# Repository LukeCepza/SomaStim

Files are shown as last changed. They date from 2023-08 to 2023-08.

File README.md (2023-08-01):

### Repository of NeuroSense Somatosensory Stimulation Devices. 
Folders are arranged in Four parts: \
 &nbsp;&nbsp;&nbsp;&nbsp;   1. Electronics Diagrams \
 &nbsp;&nbsp;&nbsp;&nbsp;   2. Firmware \
 &nbsp;&nbsp;&nbsp;&nbsp;   3. Prototypes designs \
 &nbsp;&nbsp;&nbsp;&nbsp;   4. OpenVibe Experiment Modules 

Each of these folders contain subfolders for each module (some may not include a Master Module subfolder): \
 &nbsp;&nbsp;&nbsp;&nbsp;   1. Air \
 &nbsp;&nbsp;&nbsp;&nbsp;   2. Caress \
 &nbsp;&nbsp;&nbsp;&nbsp;   3. Vibration \
 &nbsp;&nbsp;&nbsp;&nbsp;   4. Master 

There is an extra folder with other functions \
Designed by Luke Cepza \
Neurotechs Research Group

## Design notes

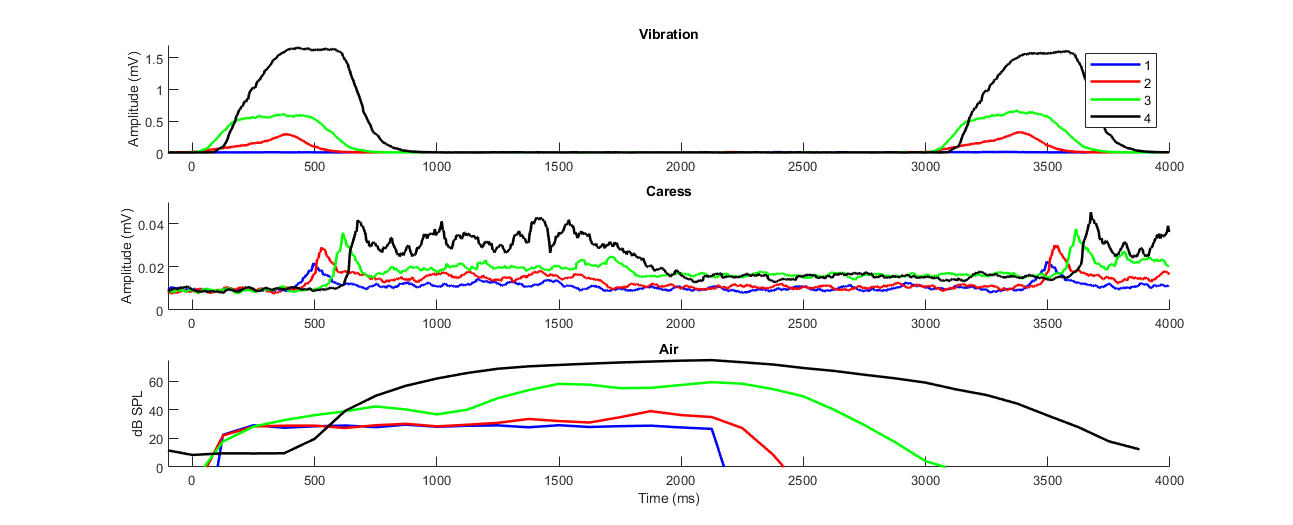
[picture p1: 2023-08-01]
Others/Matlab/sos.tif

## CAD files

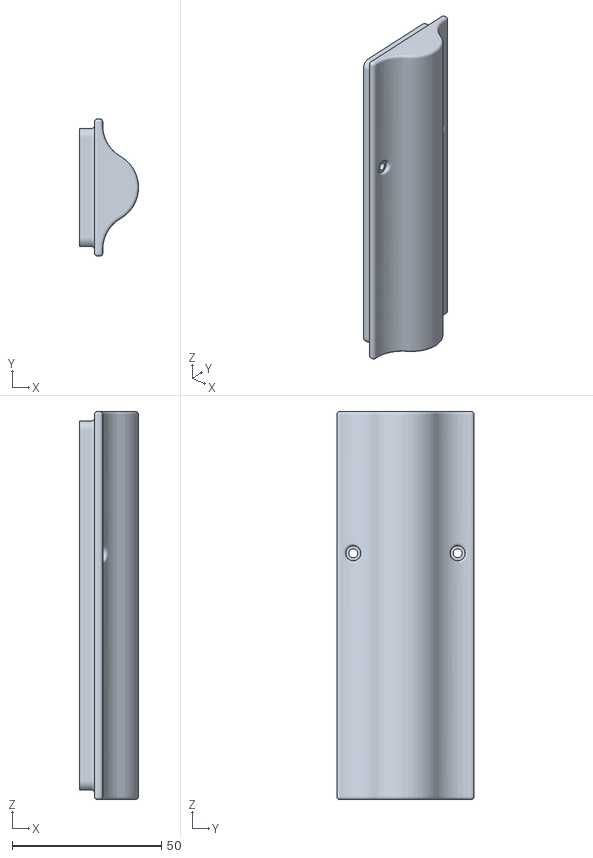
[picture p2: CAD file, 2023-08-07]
Design/VibrationModule/VibrationBox_NeuroSense_SLDPRT_STL - copia/VibracionFull - V_BatteryBoxLid-1.STL
19.8 x 46.0 x 130.0

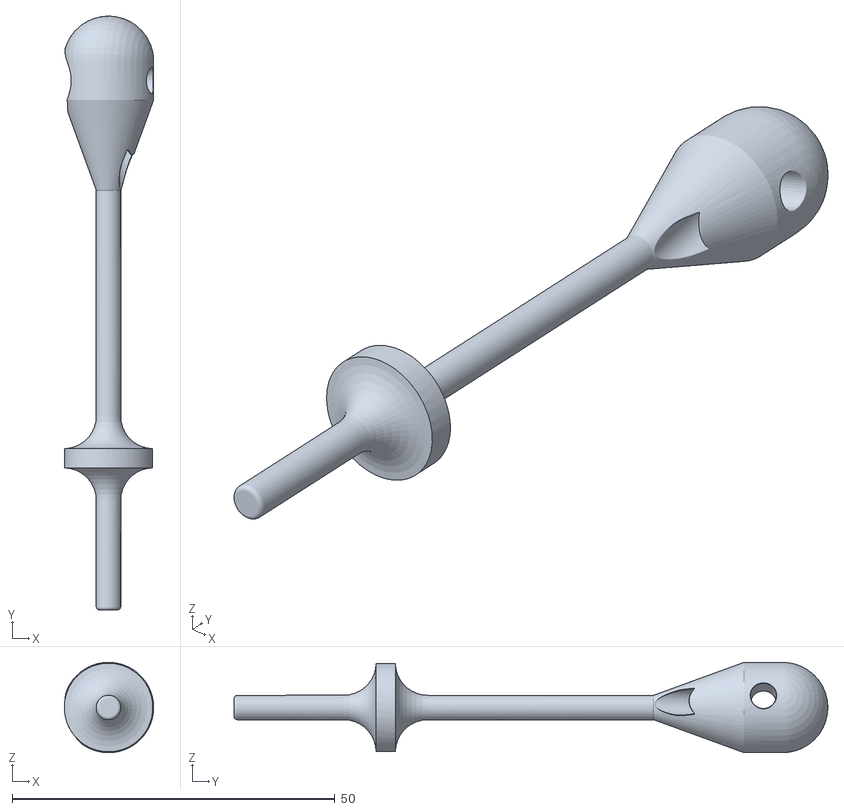
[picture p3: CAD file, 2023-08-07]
Design/VibrationModule/VibrationUpwards_NeuroSense_SLDPRT_STL/Ensamblaje1 - MotorHolderV4-1.STL
13.8 x 92.0 x 14.0

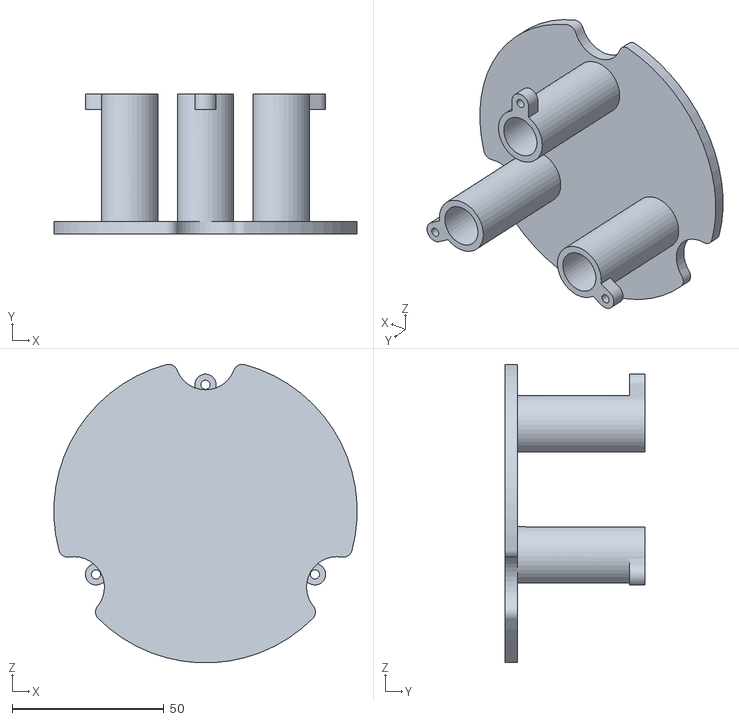
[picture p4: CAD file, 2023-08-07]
Design/VibrationModule/VibrationUpwards_NeuroSense_SLDPRT_STL/Ensamblaje1 - BaseV2-1.STL
99.9 x 46.0 x 98.3

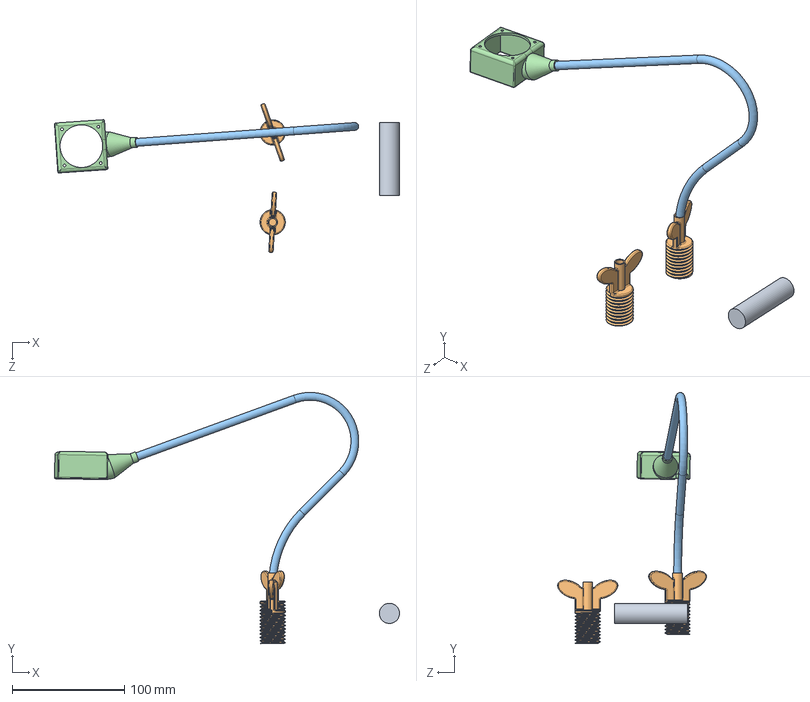
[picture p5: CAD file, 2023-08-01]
Design/AirModule_NeuroSense_SLDPRT_STL/AirModule.SLDASM
307.3 x 223.8 x 132.6 mm
A_FanScrewBase x 2
Pipe
A_FanBoxTilted

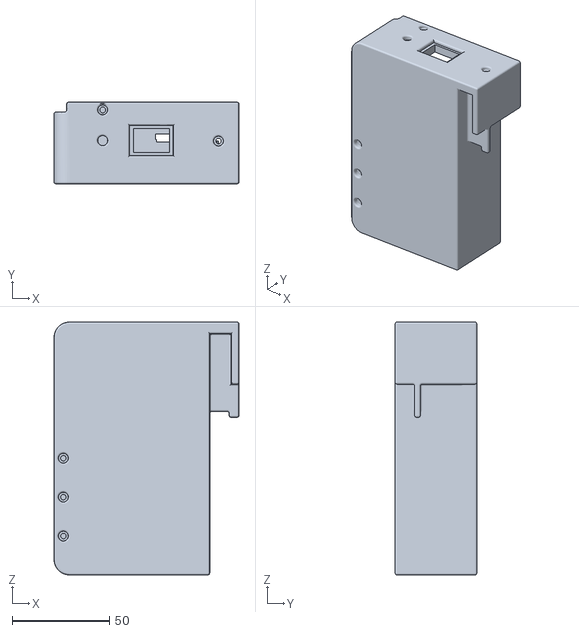
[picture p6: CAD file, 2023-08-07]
Design/VibrationModule/VibrationBox_NeuroSense_SLDPRT_STL - copia/VibracionFull - V_ElectroBox-1.STL
95.0 x 42.0 x 130.0

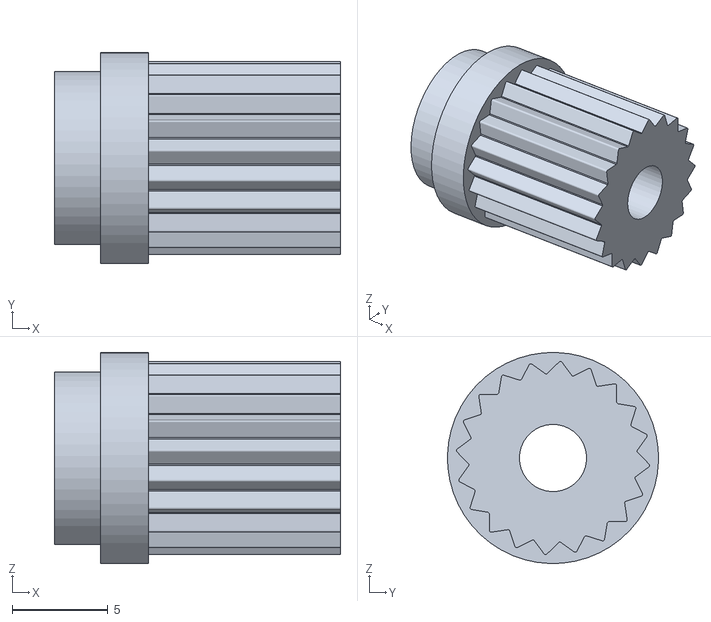
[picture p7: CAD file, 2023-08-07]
Design/CaressModule_NeuroSense_SLDPRT_STL/CaricasFull - T_MD_CouplingMotor-1.STL
14.9 x 11.0 x 11.0

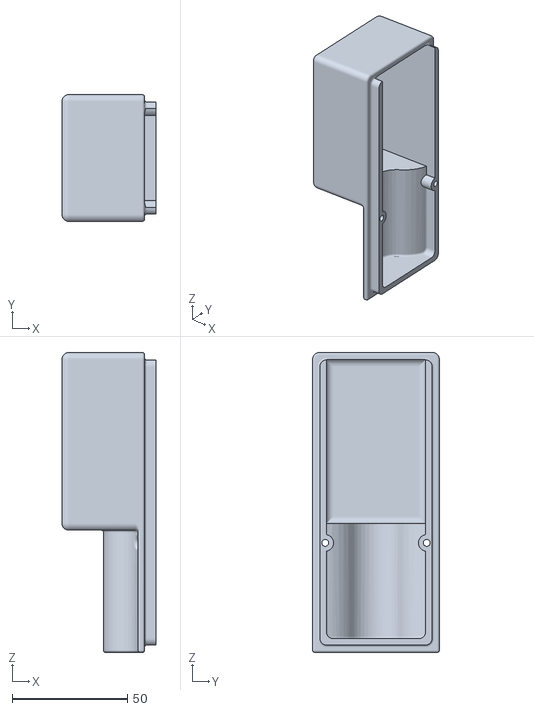
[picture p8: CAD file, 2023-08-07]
Design/CaressModule_NeuroSense_SLDPRT_STL/CaricasFull - T_MD_BatteryPackLid-1.STL
40.8 x 55.0 x 130.0

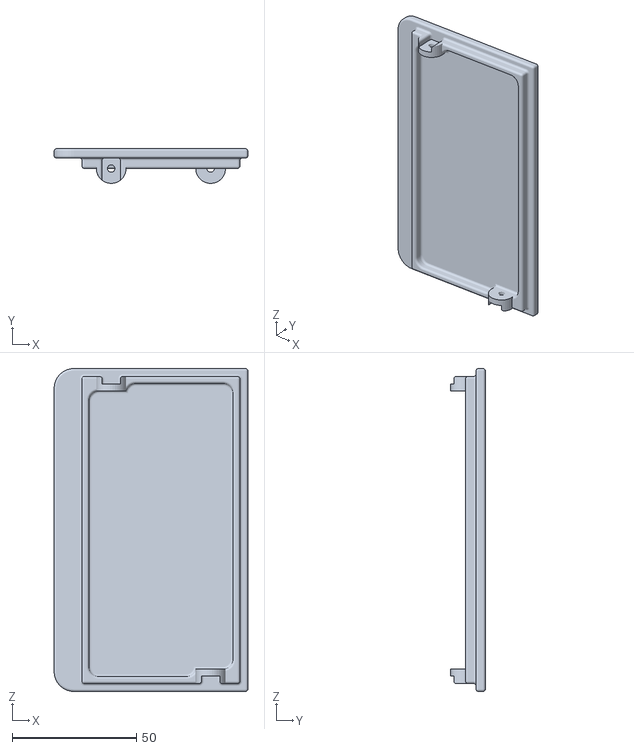
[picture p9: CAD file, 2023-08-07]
Design/VibrationModule/VibrationBox_NeuroSense_SLDPRT_STL - copia/VibracionFull - V_ElectroBoxLid-1.STL
78.0 x 14.0 x 130.0

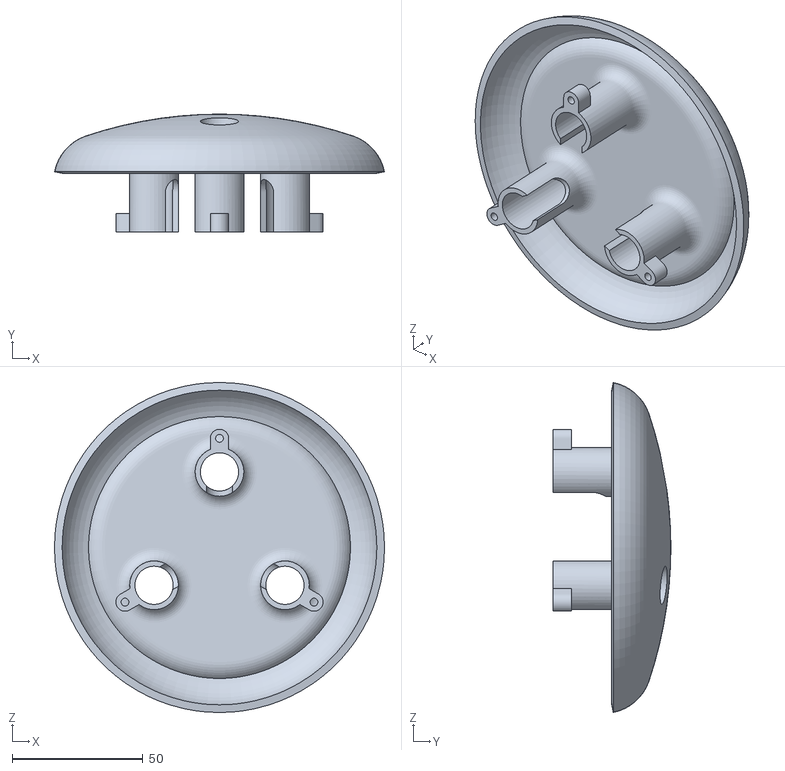
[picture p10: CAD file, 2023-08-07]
Design/VibrationModule/VibrationUpwards_NeuroSense_SLDPRT_STL/Ensamblaje1 - Upper-1.STL
126.0 x 45.0 x 126.0

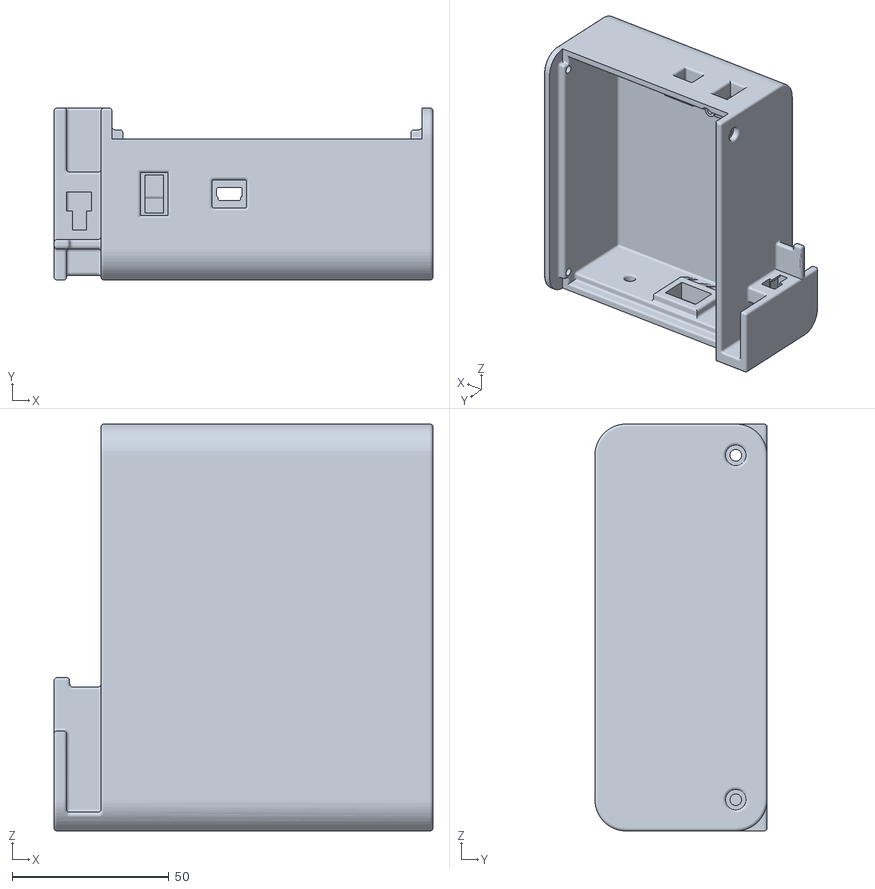
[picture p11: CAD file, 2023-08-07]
Design/CaressModule_NeuroSense_SLDPRT_STL/CaricasFull - T_MD_BaseElectroV2-1.STL
121.0 x 55.0 x 130.0

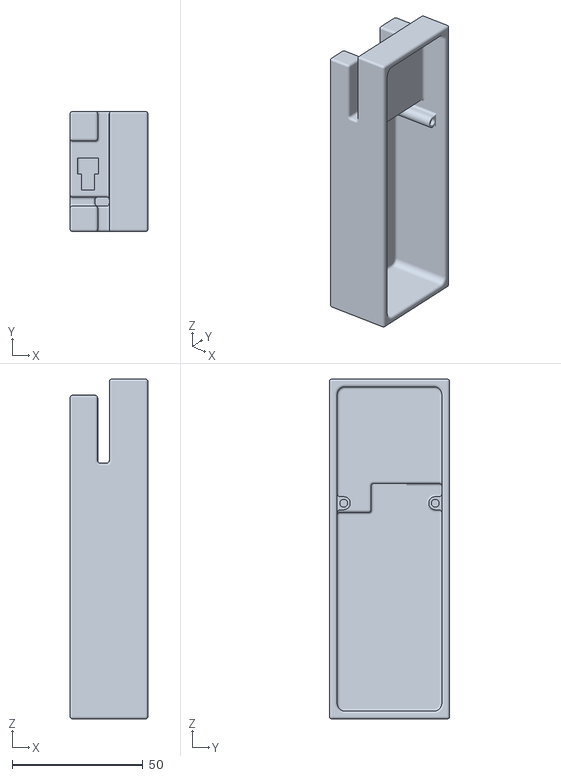
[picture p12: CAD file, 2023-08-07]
Design/VibrationModule/VibrationBox_NeuroSense_SLDPRT_STL - copia/VibracionFull - V_BatteryBox-1.STL
29.8 x 46.0 x 130.0

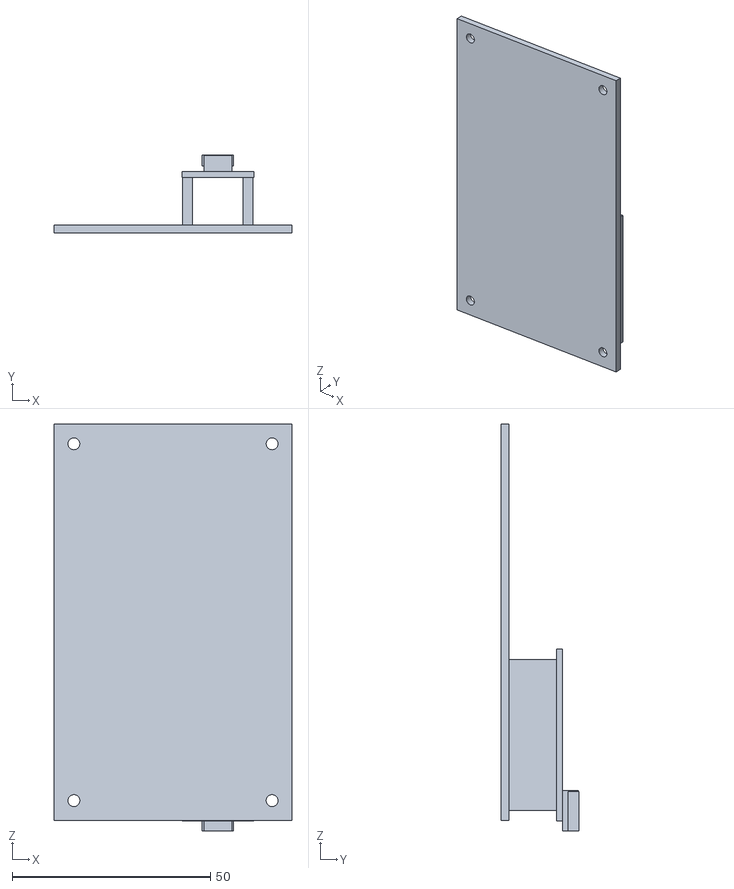
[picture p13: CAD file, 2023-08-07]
Design/VibrationModule/VibrationBox_NeuroSense_SLDPRT_STL - copia/VibracionFull - V_PCB-1.STL
60.0 x 19.7 x 102.7

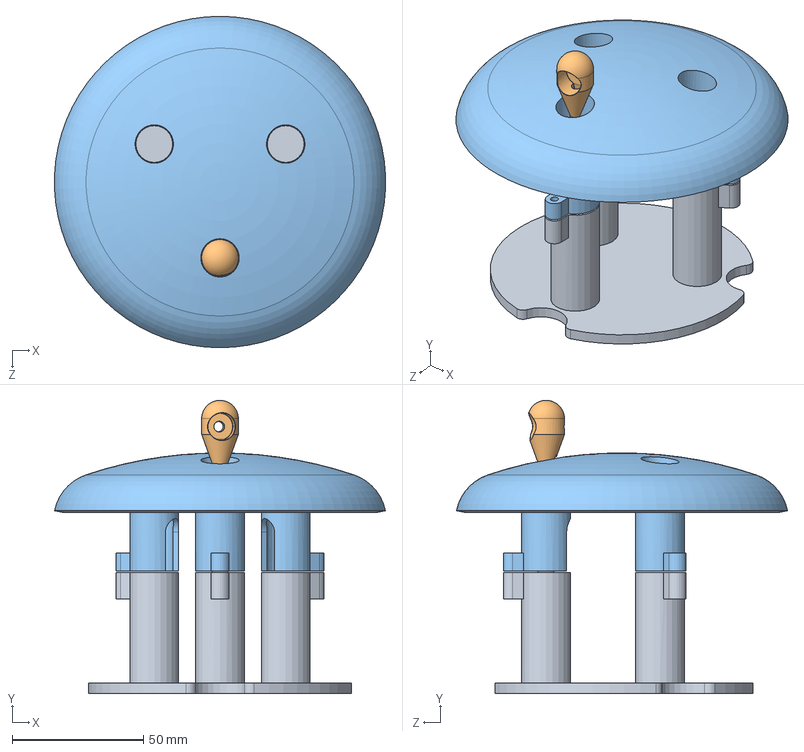
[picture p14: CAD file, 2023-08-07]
Design/VibrationModule/VibrationUpwards_NeuroSense_SLDPRT_STL/Ensamblaje1.SLDASM
125.9 x 111.6 x 126.0 mm
BaseV2
MotorHolderV4
Upper

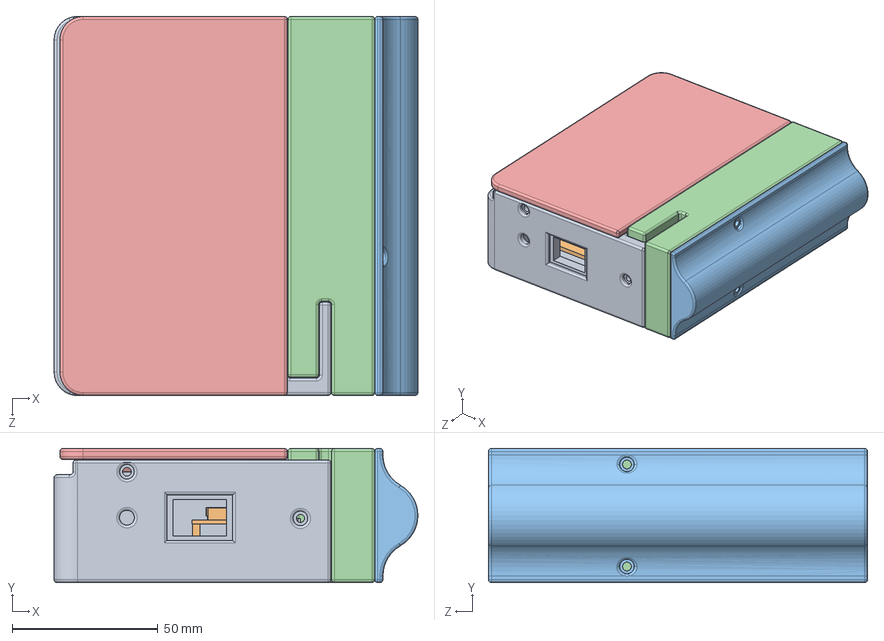
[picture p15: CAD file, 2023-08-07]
Design/VibrationModule/VibrationBox_NeuroSense_SLDPRT_STL - copia/VibracionFull.SLDASM
124.8 x 46.0 x 130.0 mm
V_ElectroBox
V_PCB
V_BatteryBoxLid
V_BatteryBox
V_ElectroBoxLid

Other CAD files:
Design/CaressModule_NeuroSense_SLDPRT_STL/CaricasFull - T_MD_LoadCell-1.STL
Design/CaressModule_NeuroSense_SLDPRT_STL/CaricasFull - T_MD_RollerAxis-1.STL
Design/CaressModule_NeuroSense_SLDPRT_STL/CaricasFull - T_MD_MotorSupport-1.STL
Design/CaressModule_NeuroSense_SLDPRT_STL/CaricasFull - T_MD_LateralBehind-1.STL
Design/AirModule_NeuroSense_SLDPRT_STL/18650.SLDPRT
Design/AirModule_NeuroSense_SLDPRT_STL/A_BatteryBox.SLDPRT
Design/AirModule_NeuroSense_SLDPRT_STL/A_BatteryBoxLid.SLDPRT
Design/AirModule_NeuroSense_SLDPRT_STL/A_ElectroBox.SLDPRT
Design/AirModule_NeuroSense_SLDPRT_STL/A_ElectroBoxLid.SLDPRT
Design/AirModule_NeuroSense_SLDPRT_STL/A_FanBoxTilted.SLDPRT
Design/AirModule_NeuroSense_SLDPRT_STL/A_FanScrewBase.SLDPRT
Design/AirModule_NeuroSense_SLDPRT_STL/AirModule - 18650-1.STL
Design/AirModule_NeuroSense_SLDPRT_STL/AirModule - A_BatteryBox-1.STL
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

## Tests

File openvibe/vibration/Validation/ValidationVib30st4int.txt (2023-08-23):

-- this function is called when the box is initialized
function initialize(box)
	dofile(box:get_config("${Path_Data}") .. "/plugins/stimulation/lua-stimulator-stimcodes.lua")
end

-- this function is called when the box is uninitialized
function uninitialize(box)
	io.write("uninitialize has been calle d\n")
end

function process(box)
	io.write("process has been called\n")
	box:send_stimulation(1,33084,2,0)	--Start LSL communication
		
	-- stimuli labels
	-- 33032, vibration 1/4
	-- 33033, vibration 2/4
	-- 33034, vibration 3/4
	-- 33035, vibration 4/4
	-- 33042, stop stimulus
	
box:send_stimulation(1, 33032, 5, 0)
box:send_stimulation(1, 33032, 7, 0)
box:send_stimulation(1, 33032, 9, 0)
box:send_stimulation(1, 33032, 11, 0)
box:send_stimulation(1, 33032, 13, 0)
box:send_stimulation(1, 33032, 15, 0)
box:send_stimulation(1, 33032, 17, 0)
box:send_stimulation(1, 33032, 19, 0)
box:send_stimulation(1, 33032, 21, 0)
box:send_stimulation(1, 33032, 23, 0)
box:send_stimulation(1, 33032, 25, 0)
box:send_stimulation(1, 33032, 27, 0)
box:send_stimulation(1, 33032, 29, 0)
box:send_stimulation(1, 33032, 31, 0)
box:send_stimulation(1, 33032, 33, 0)
box:send_stimulation(1, 33032, 35, 0)
box:send_stimulation(1, 33032, 37, 0)
box:send_stimulation(1, 33032, 39, 0)
box:send_stimulation(1, 33032, 41, 0)
box:send_stimulation(1, 33032, 43, 0)
box:send_stimulation(1, 33032, 45, 0)
box:send_stimulation(1, 33032, 47, 0)
box:send_stimulation(1, 33032, 49, 0)
box:send_stimulation(1, 33032, 51, 0)
box:send_stimulation(1, 33032, 53, 0)
box:send_stimulation(1, 33032, 55, 0)
box:send_stimulation(1, 33032, 57, 0)
box:send_stimulation(1, 33032, 59, 0)
box:send_stimulation(1, 33032, 61, 0)
box:send_stimulation(1, 33032, 63, 0)
box:send_stimulation(1, 33042, 5.5, 0)
box:send_stimulation(1, 33042, 7.5, 0)
box:send_stimulation(1, 33042, 9.5, 0)
box:send_stimulation(1, 33042, 11.5, 0)
box:send_stimulation(1, 33042, 13.5, 0)
box:send_stimulation(1, 33042, 15.5, 0)
box:send_stimulation(1, 33042, 17.5, 0)
box:send_stimulation(1, 33042, 19.5, 0)
box:send_stimulation(1, 33042, 21.5, 0)
box:send_stimulation(1, 33042, 23.5, 0)
box:send_stimulation(1, 33042, 25.5, 0)
box:send_stimulation(1, 33042, 27.5, 0)
box:send_stimulation(1, 33042, 29.5, 0)
box:send_stimulation(1, 33042, 31.5, 0)
box:send_stimulation(1, 33042, 33.5, 0)
box:send_stimulation(1, 33042, 35.5, 0)
box:send_stimulation(1, 33042, 37.5, 0)
box:send_stimulation(1, 33042, 39.5, 0)
box:send_stimulation(1, 33042, 41.5, 0)
box:send_stimulation(1, 33042, 43.5, 0)
box:send_stimulation(1, 33042, 45.5, 0)
box:send_stimulation(1, 33042, 47.5, 0)
box:send_stimulation(1, 33042, 49.5, 0)
box:send_stimulation(1, 33042, 51.5, 0)
box:send_stimulation(1, 33042, 53.5, 0)
box:send_stimulation(1, 33042, 55.5, 0)
box:send_stimulation(1, 33042, 57.5, 0)
box:send_stimulation(1, 33042, 59.5, 0)
box:send_stimulation(1, 33042, 61.5, 0)
box:send_stimulation(1, 33042, 63.5, 0)

box:send_stimulation(1, 33033, 65, 0)
box:send_stimulation(1, 33033, 67, 0)
box:send_stimulation(1, 33033, 69, 0)
box:send_stimulation(1, 33033, 71, 0)
box:send_stimulation(1, 33033, 73, 0)
box:send_stimulation(1, 33033, 75, 0)
box:send_stimulation(1, 33033, 77, 0)
box:send_stimulation(1, 33033, 79, 0)
box:send_stimulation(1, 33033, 81, 0)
box:send_stimulation(1, 33033, 83, 0)
box:send_stimulation(1, 33033, 85, 0)
box:send_stimulation(1, 33033, 87, 0)
box:send_stimulation(1, 33033, 89, 0)
box:send_stimulation(1, 33033, 91, 0)
box:send_stimulation(1, 33033, 93, 0)
box:send_stimulation(1, 33033, 95, 0)
box:send_stimulation(1, 33033, 97, 0)
box:send_stimulation(1, 33033, 99, 0)
box:send_stimulation(1, 33033, 101, 0)
box:send_stimulation(1, 33033, 103, 0)
box:send_stimulation(1, 33033, 105, 0)
box:send_stimulation(1, 33033, 107, 0)
box:send_stimulation(1, 33033, 109, 0)
box:send_stimulation(1, 33033, 111, 0)
box:send_stimulation(1, 33033, 113, 0)
box:send_stimulation(1, 33033, 115, 0)
box:send_stimulation(1, 33033, 117, 0)
box:send_stimulation(1, 33033, 119, 0)
box:send_stimulation(1, 33033, 121, 0)
box:send_stimulation(1, 33033, 123, 0)
box:send_stimulation(1, 33042, 65.5, 0)
box:send_stimulation(1, 33042, 67.5, 0)
box:send_stimulation(1, 33042, 69.5, 0)
box:send_stimulation(1, 33042, 71.5, 0)
box:send_stimulation(1, 33042, 73.5, 0)
box:send_stimulation(1, 33042, 75.5, 0)
box:send_stimulation(1, 33042, 77.5, 0)
box:send_stimulation(1, 33042, 79.5, 0)
box:send_stimulation(1, 33042, 81.5, 0)
box:send_stimulation(1, 33042, 83.5, 0)
box:send_stimulation(1, 33042, 85.5, 0)
box:send_stimulation(1, 33042, 87.5, 0)
box:send_stimulation(1, 33042, 89.5, 0)
box:send_stimulation(1, 33042, 91.5, 0)
box:send_stimulation(1, 33042, 93.5, 0)
box:send_stimulation(1, 33042, 95.5, 0)
box:send_stimulation(1, 33042, 97.5, 0)
box:send_stimulation(1, 33042, 99.5, 0)
box:send_stimulation(1, 33042, 101.5, 0)
box:send_stimulation(1, 33042, 103.5, 0)
box:send_stimulation(1, 33042, 105.5, 0)
box:send_stimulation(1, 33042, 107.5, 0)
box:send_stimulation(1, 33042, 109.5, 0)
box:send_stimulation(1, 33042, 111.5, 0)
box:send_stimulation(1, 33042, 113.5, 0)
box:send_stimulation(1, 33042, 115.5, 0)
box:send_stimulation(1, 33042, 117.5, 0)
box:send_stimulation(1, 33042, 119.5, 0)
box:send_stimulation(1, 33042, 121.5, 0)
box:send_stimulation(1, 33042, 123.5, 0)

box:send_stimulation(1, 33034, 125, 0)
box:send_stimulation(1, 33034, 127, 0)
box:send_stimulation(1, 33034, 129, 0)
box:send_stimulation(1, 33034, 131, 0)
box:send_stimulation(1, 33034, 133, 0)
box:send_stimulation(1, 33034, 135, 0)
box:send_stimulation(1, 33034, 137, 0)
box:send_stimulation(1, 33034, 139, 0)
box:send_stimulation(1, 33034, 141, 0)
box:send_stimulation(1, 33034, 143, 0)
box:send_stimulation(1, 33034, 145, 0)
box:send_stimulation(1, 33034, 147, 0)
box:send_stimulation(1, 33034, 149, 0)
box:send_stimulation(1, 33034, 151, 0)
box:send_stimulation(1, 33034, 153, 0)
box:send_stimulation(1, 33034, 155, 0)
box:send_stimulation(1, 33034, 157, 0)
box:send_stimulation(1, 33034, 159, 0)
box:send_stimulation(1, 33034, 161, 0)
box:send_stimulation(1, 33034, 163, 0)
box:send_stimulation(1, 33034, 165, 0)
box:send_stimulation(1, 33034, 167, 0)
box:send_stimulation(1, 33034, 169, 0)
box:send_stimulation(1, 33034, 171, 0)
box:send_stimulation(1, 33034, 173, 0)
box:send_stimulation(1, 33034, 175, 0)
box:send_stimulation(1, 33034, 177, 0)
box:send_stimulation(1, 33034, 179, 0)
box:send_stimulation(1, 33034, 181, 0)
box:send_stimulation(1, 33034, 183, 0)
box:send_stimulation(1, 33042, 125.5, 0)
box:send_stimulation(1, 33042, 127.5, 0)
box:send_stimulation(1, 33042, 129.5, 0)
box:send_stimulation(1, 33042, 131.5, 0)
box:send_stimulation(1, 33042, 133.5, 0)
box:send_stimulation(1, 33042, 135.5, 0)
box:send_stimulation(1, 33042, 137.5, 0)
box:send_stimulation(1, 33042, 139.5, 0)
box:send_stimulation(1, 33042, 141.5, 0)
box:send_stimulation(1, 33042, 143.5, 0)
box:send_stimulation(1, 33042, 145.5, 0)
box:send_stimulation(1, 33042, 147.5, 0)
box:send_stimulation(1, 33042, 149.5, 0)
box:send_stimulation(1, 33042, 151.5, 0)
box:send_stimulation(1, 33042, 153.5, 0)
box:send_stimulation(1, 33042, 155.5, 0)
box:send_stimulation(1, 33042, 157.5, 0)
box:send_stimulation(1, 33042, 159.5, 0)
box:send_stimulation(1, 33042, 161.5, 0)
box:send_stimulation(1, 33042, 163.5, 0)
box:send_stimulation(1, 33042, 165.5, 0)
box:send_stimulation(1, 33042, 167.5, 0)
box:send_stimulation(1, 33042, 169.5, 0)
box:send_stimulation(1, 33042, 171.5, 0)
box:send_stimulation(1, 33042, 173.5, 0)
box:send_stimulation(1, 33042, 175.5, 0)
box:send_stimulation(1, 33042, 177.5, 0)
box:send_stimulation(1, 33042, 179.5, 0)
box:send_stimulation(1, 33042, 181.5, 0)
box:send_stimulation(1, 33042, 183.5, 0)

box:send_stimulation(1, 33035, 185, 0)
box:send_stimulation(1, 33035, 187, 0)
box:send_stimulation(1, 33035, 189, 0)
box:send_stimulation(1, 33035, 191, 0)
box:send_stimulation(1, 33035, 193, 0)
box:send_stimulation(1, 33035, 195, 0)
box:send_stimulation(1, 33035, 197, 0)
box:send_stimulation(1, 33035, 199, 0)
box:send_stimulation(1, 33035, 201, 0)
box:send_stimulation(1, 33035, 203, 0)
box:send_stimulation(1, 33035, 205, 0)
box:send_stimulation(1, 33035, 207, 0)
box:send_stimulation(1, 33035, 209, 0)
box:send_stimulation(1, 33035, 211, 0)
box:send_stimulation(1, 33035, 213, 0)
box:send_stimulation(1, 33035, 215, 0)
box:send_stimulation(1, 33035, 217, 0)
box:send_stimulation(1, 33035, 219, 0)
box:send_stimulation(1, 33035, 221, 0)
box:send_stimulation(1, 33035, 223, 0)
box:send_stimulation(1, 33035, 225, 0)
box:send_stimulation(1, 33035, 227, 0)
box:send_stimulation(1, 33035, 229, 0)
box:send_stimulation(1, 33035, 231, 0)
box:send_stimulation(1, 33035, 233, 0)
box:send_stimulation(1, 33035, 235, 0)
box:send_stimulation(1, 33035, 237, 0)
box:send_stimulation(1, 33035, 239, 0)
box:send_stimulation(1, 33035, 241, 0)
box:send_stimulation(1, 33035, 243, 0)
box:send_stimulation(1, 33042, 185.5, 0)
box:send_stimulation(1, 33042, 187.5, 0)
box:send_stimulation(1, 33042, 189.5, 0)
box:send_stimulation(1, 33042, 191.5, 0)
box:send_stimulation(1, 33042, 193.5, 0)
box:send_stimulation(1, 33042, 195.5, 0)
box:send_stimulation(1, 33042, 197.5, 0)
box:send_stimulation(1, 33042, 199.5, 0)
box:send_stimulation(1, 33042, 201.5, 0)
box:send_stimulation(1, 33042, 203.5, 0)
box:send_stimulation(1, 33042, 205.5, 0)
box:send_stimulation(1, 33042, 207.5, 0)
box:send_stimulation(1, 33042, 209.5, 0)
box:send_stimulation(1, 33042, 211.5, 0)
box:send_stimulation(1, 33042, 213.5, 0)
box:send_stimulation(1, 33042, 215.5, 0)
box:send_stimulation(1, 33042, 217.5, 0)
box:send_stimulation(1, 33042, 219.5, 0)
box:send_stimulation(1, 33042, 221.5, 0)
box:send_stimulation(1, 33042, 223.5, 0)
box:send_stimulation(1, 33042, 225.5, 0)
box:send_stimulation(1, 33042, 227.5, 0)
box:send_stimulation(1, 33042, 229.5, 0)
box:send_stimulation(1, 33042, 231.5, 0)
box:send_stimulation(1, 33042, 233.5, 0)
box:send_stimulation(1, 33042, 235.5, 0)
box:send_stimulation(1, 33042, 237.5, 0)
box:send_stimulation(1, 33042, 239.5, 0)
box:send_stimulation(1, 33042, 241.5, 0)
box:send_stimulation(1, 33042, 243.5, 0)

	box:send_stimulation(1, 32770, 303, 0)	-- End paradigm
	box:send_stimulation(1, 32770, 305, 0) 
	
	box:sleep()				-- releases cpu

end

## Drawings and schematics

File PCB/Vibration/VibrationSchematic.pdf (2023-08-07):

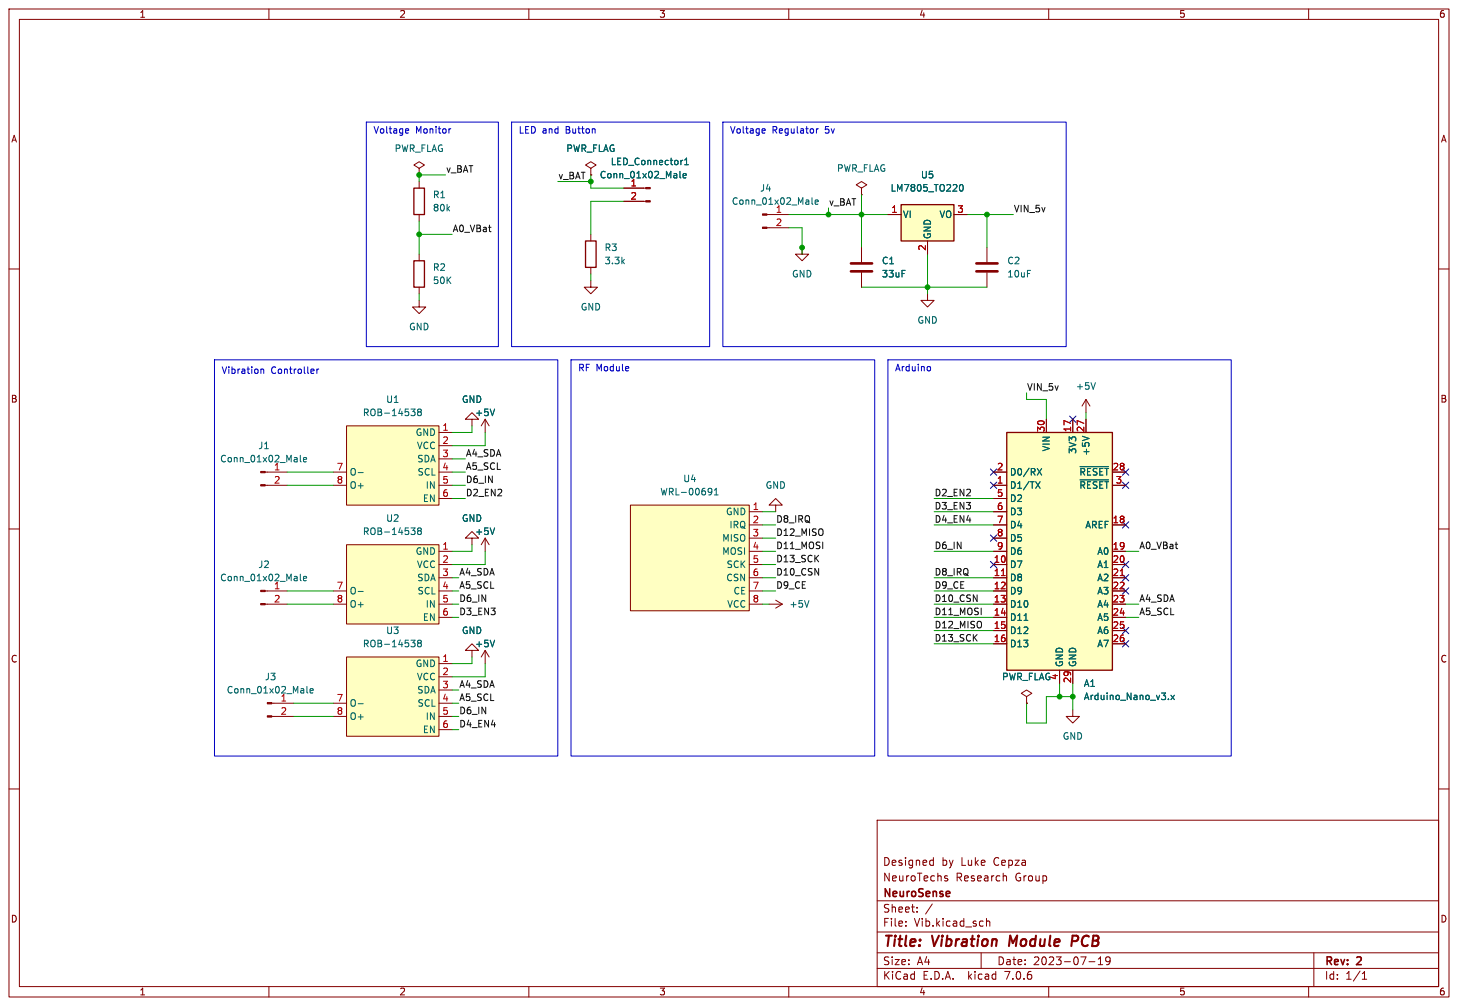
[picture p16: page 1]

Id: 1/1 Title: Vibration Module PCB

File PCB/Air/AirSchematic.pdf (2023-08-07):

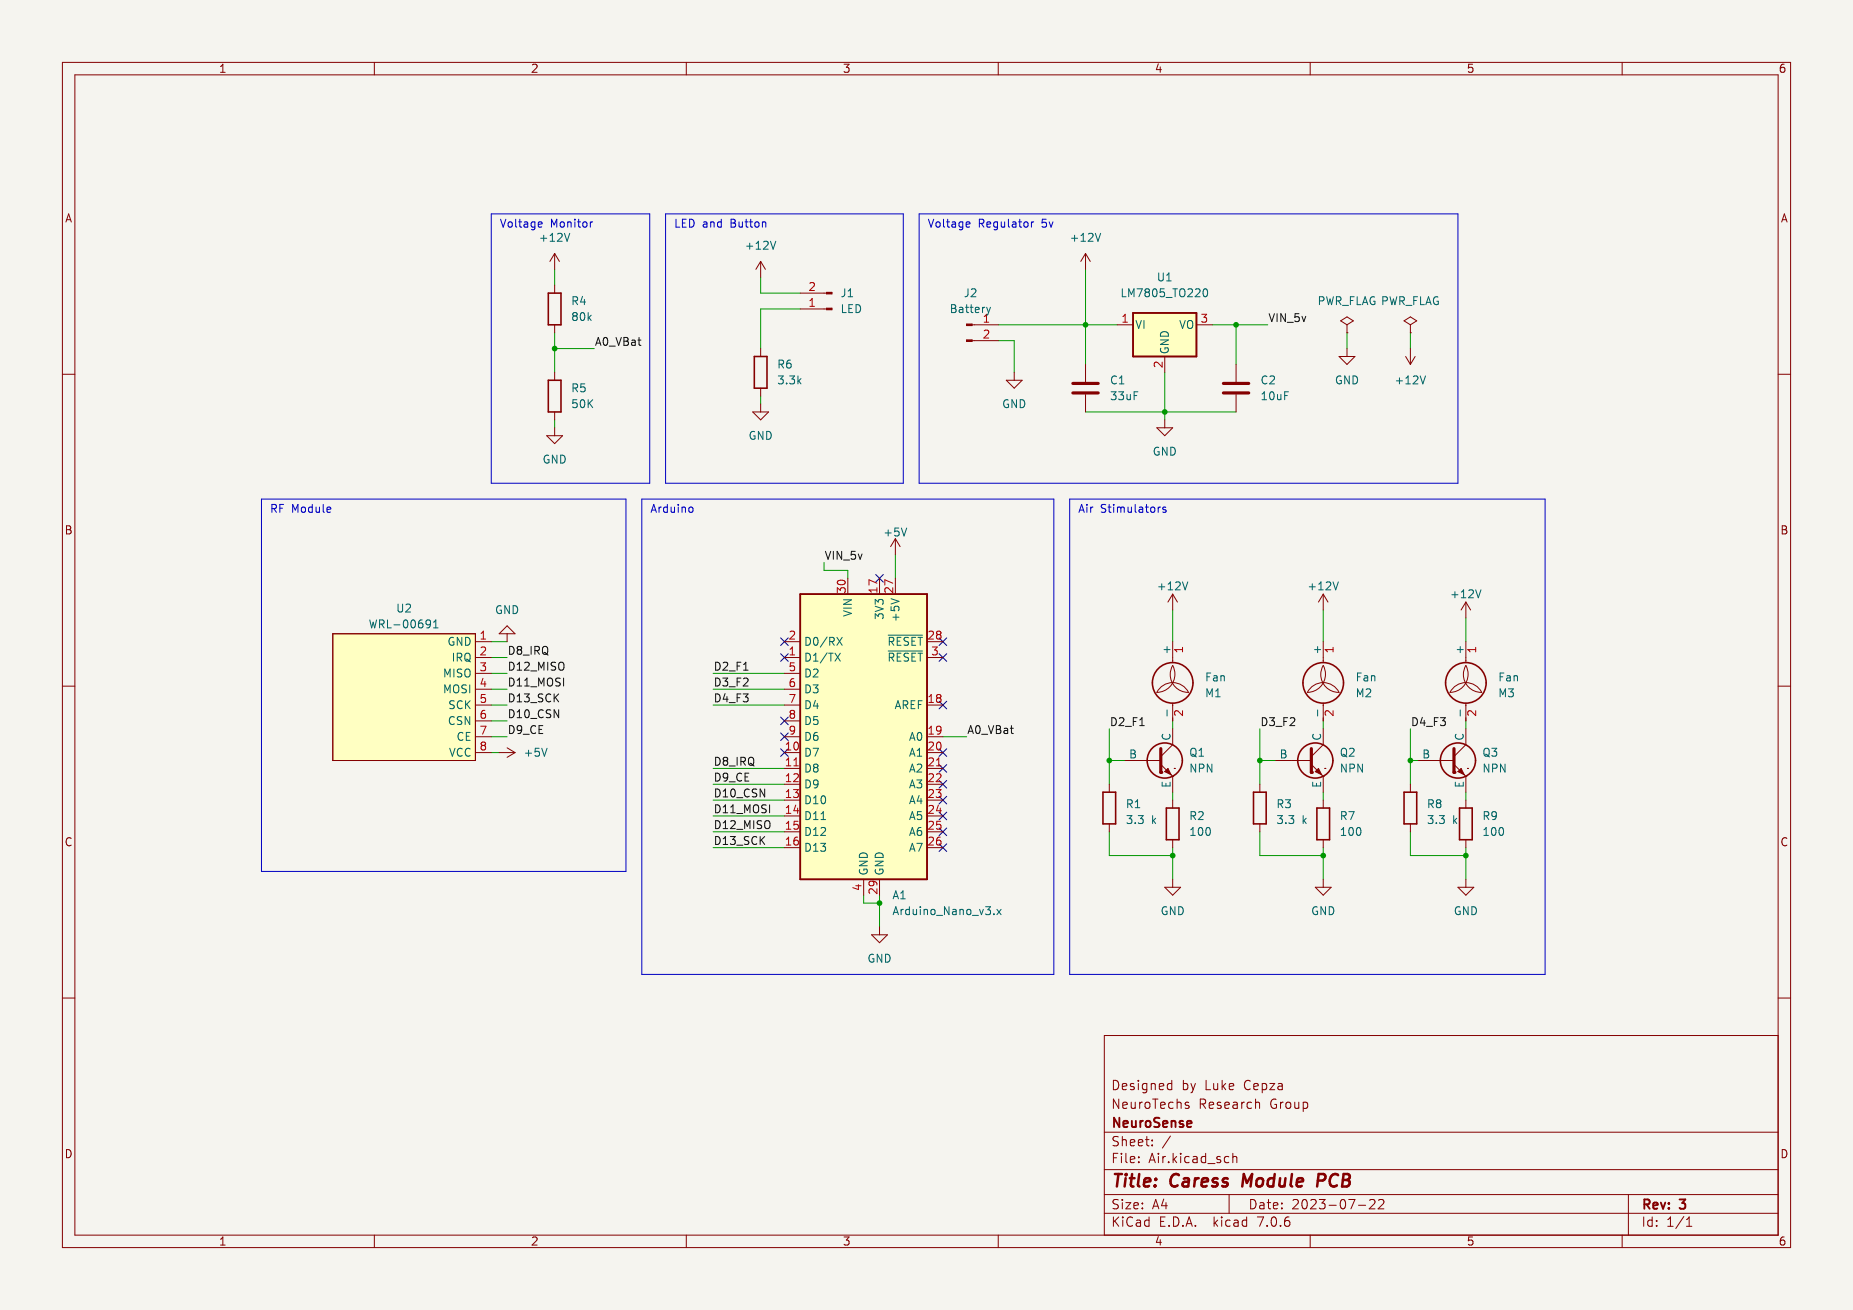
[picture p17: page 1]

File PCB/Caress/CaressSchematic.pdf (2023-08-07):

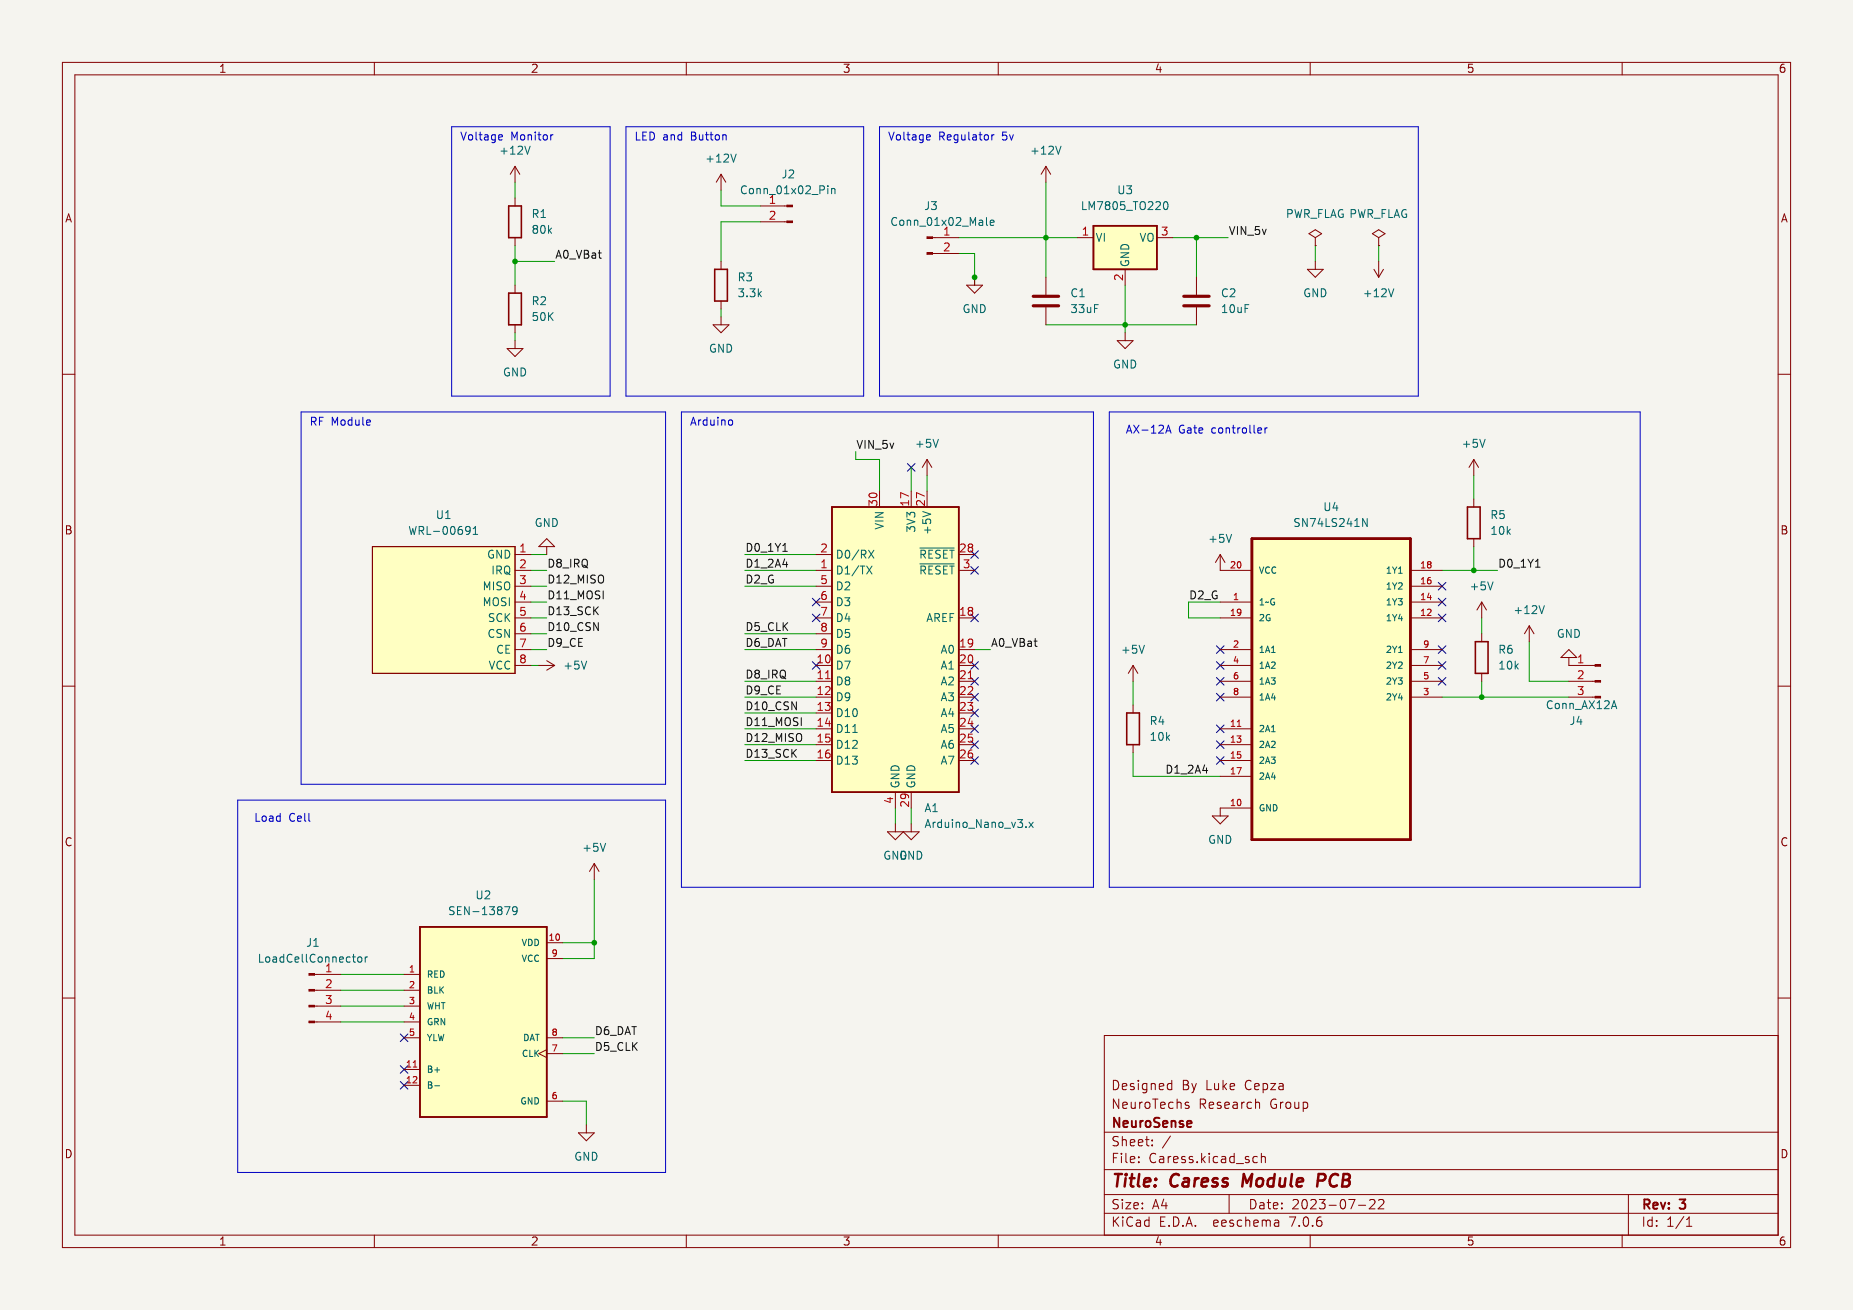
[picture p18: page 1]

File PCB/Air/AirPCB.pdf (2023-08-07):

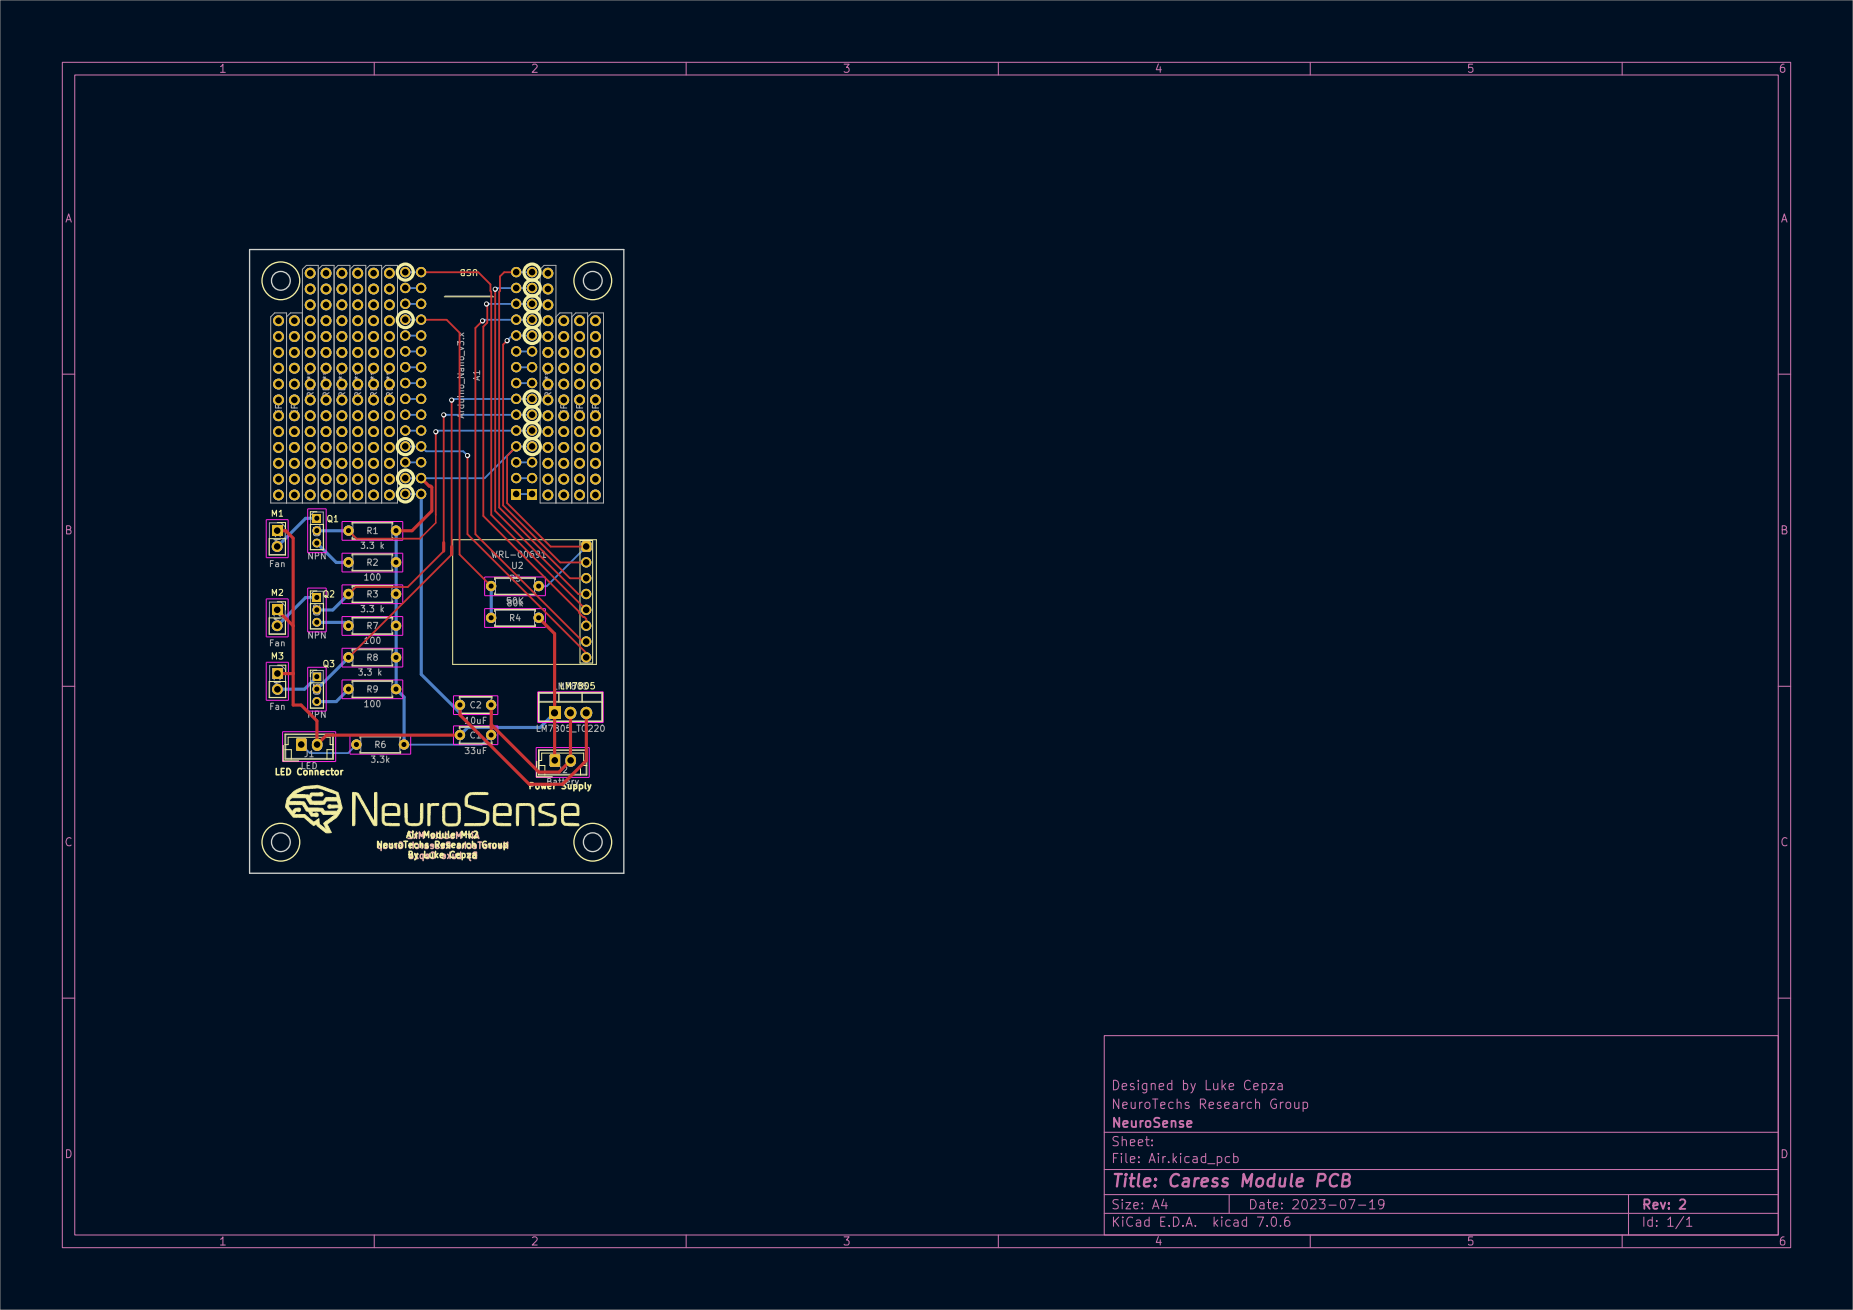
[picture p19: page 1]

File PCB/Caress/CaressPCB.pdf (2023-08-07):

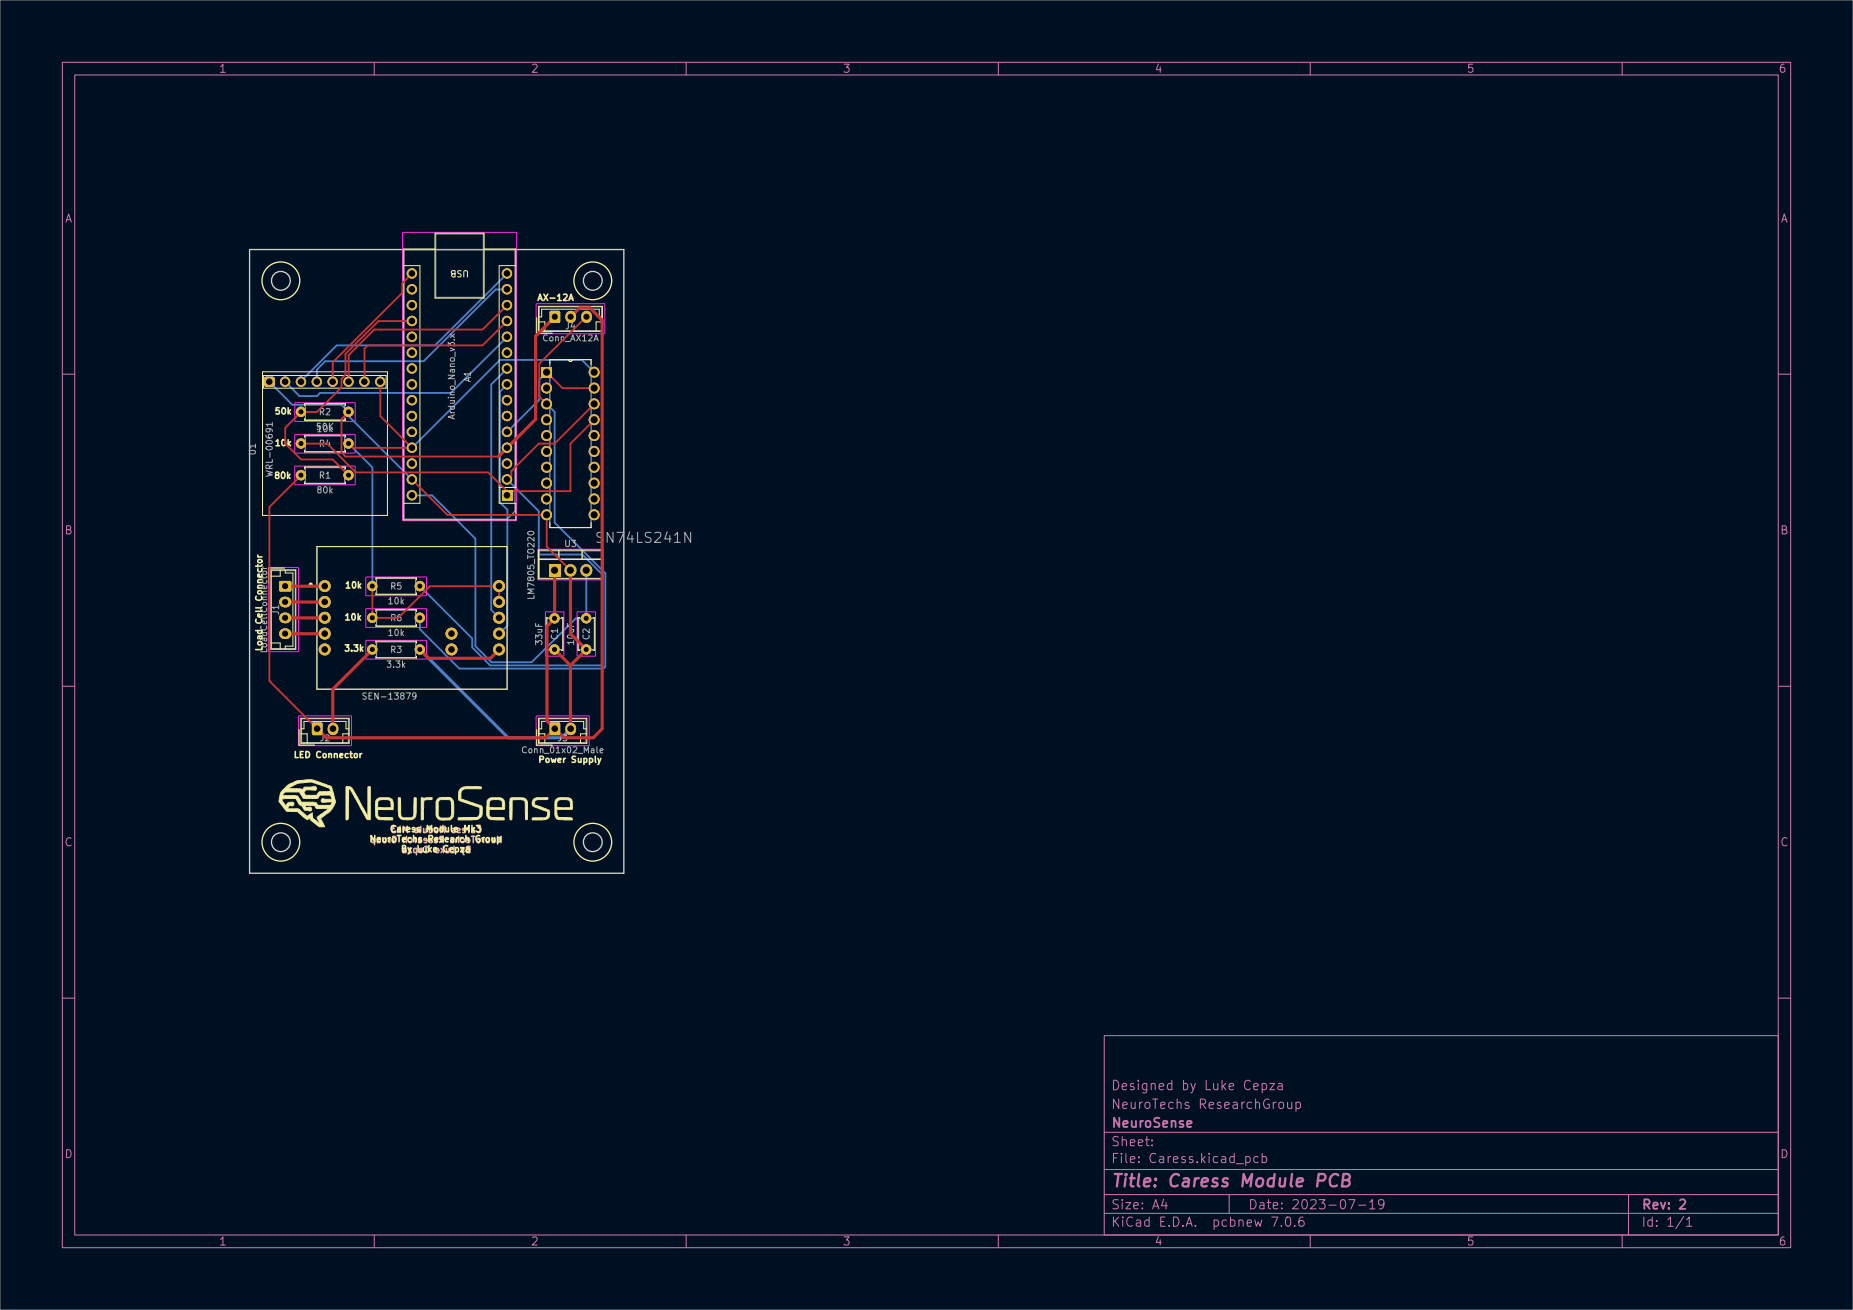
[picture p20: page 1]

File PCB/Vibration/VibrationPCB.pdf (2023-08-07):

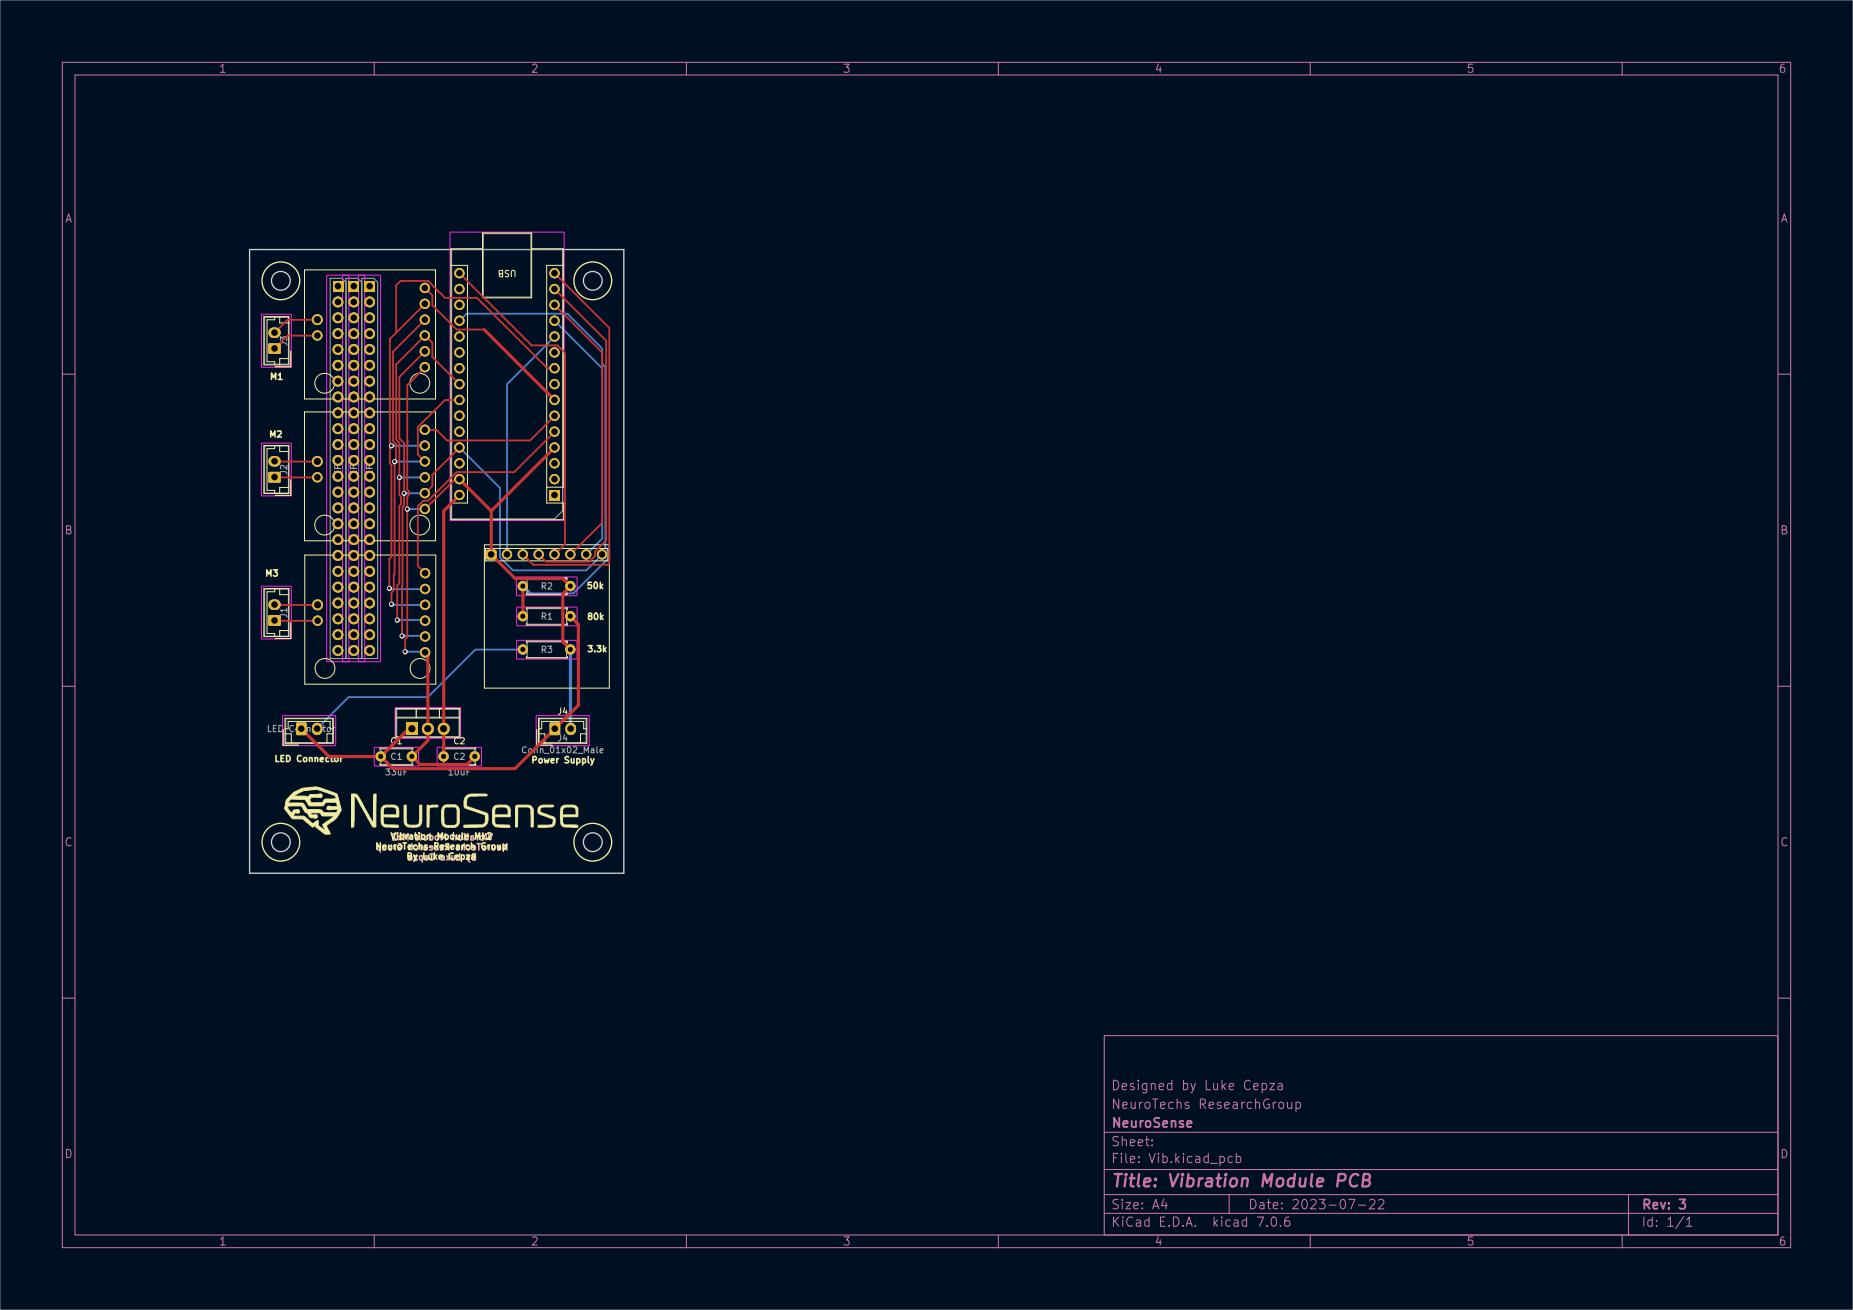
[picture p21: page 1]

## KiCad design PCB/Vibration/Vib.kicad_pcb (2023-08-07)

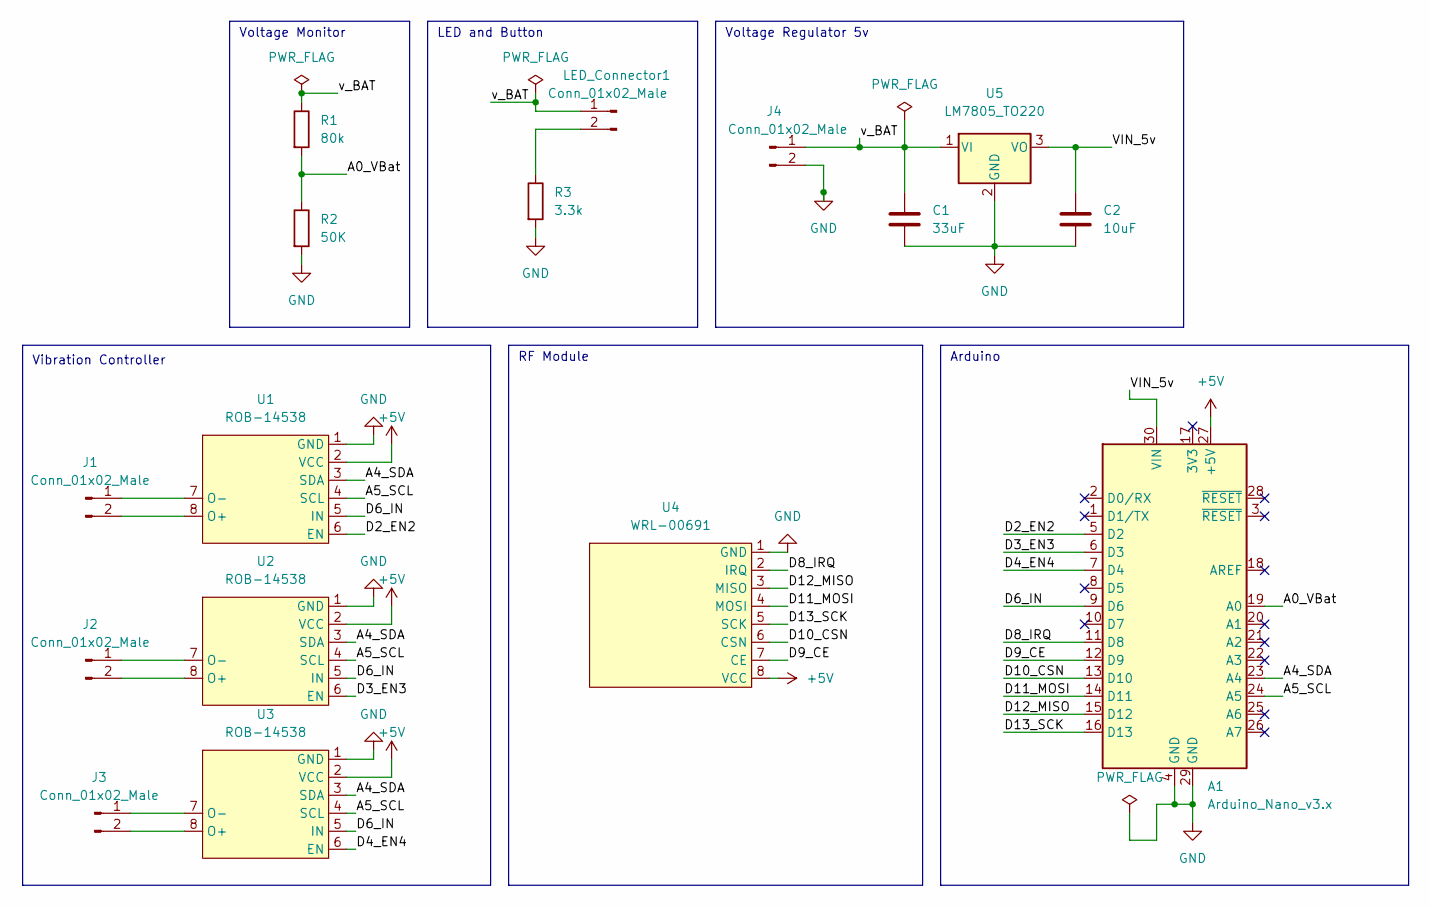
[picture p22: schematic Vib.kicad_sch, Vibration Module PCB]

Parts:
A1: Arduino_Nano_v3.x; Arduino_Nano
C1: 33uF; C_Disc_D5.0mm_W2.5mm_P5.00mm
C2: 10uF; C_Disc_D5.0mm_W2.5mm_P5.00mm
J1, J2, J3, J4: Conn_01x02_Male; JST_EH_B2B-EH-A_1x02_P2.50mm_Vertical
LED_Connector1: Conn_01x02_Male; JST_EH_B2B-EH-A_1x02_P2.50mm_Vertical
R1: 80k; R_Axial_DIN0207_L6.3mm_D2.5mm_P7.62mm_Horizontal
R2: 50K; R_Axial_DIN0207_L6.3mm_D2.5mm_P7.62mm_Horizontal
R3: 3.3k; R_Axial_DIN0207_L6.3mm_D2.5mm_P7.62mm_Horizontal
U1, U2, U3: ROB-14538; ROB_14538
U4: WRL-00691
U5: LM7805_TO220; TO-220-3_Vertical

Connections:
+5V: A1.27 (+5V), U1.2 (VCC), U2.2 (VCC), U3.2 (VCC), U4.8 (VCC)
/A0_VBat: A1.19 (A0), R1.2, R2.1
/A4_SDA: A1.23 (A4), U1.3 (SDA), U2.3 (SDA), U3.3 (SDA)
/A5_SCL: A1.24 (A5), U1.4 (SCL), U2.4 (SCL), U3.4 (SCL)
/D2_EN2: A1.5 (D2), U1.6 (EN)
/D3_EN3: A1.6 (D3), U2.6 (EN)
/D4_EN4: A1.7 (D4), U3.6 (EN)
/D6_IN: A1.9 (D6), U1.5 (IN), U2.5 (IN), U3.5 (IN)
/D8_IRQ: A1.11 (D8), U4.2 (IRQ)
/D9_CE: A1.12 (D9), U4.7 (CE)
/D10_CSN: A1.13 (D10), U4.6 (CSN)
/D11_MOSI: A1.14 (D11), U4.4 (MOSI)
/D12_MISO: A1.15 (D12), U4.3 (MISO)
/D13_SCK: A1.16 (D13), U4.5 (SCK)
/VIN_5v: A1.30 (VIN), C2.1, U5.3 (VO)
/v_BAT: C1.1, J4.1, LED_Connector1.1, R1.1, U5.1 (VI); also elsewhere on the board
GND: A1.4 (GND), A1.29 (GND), C1.2, C2.2, J4.2, R2.2, R3.2, U1.1 (GND), U2.1 (GND), U3.1 (GND), U4.1 (GND), U5.2 (GND)
unnamed: J1.1, U1.7 (O-)
unnamed: J1.2, U1.8 (O+)
unnamed: J2.1, U2.7 (O-)
unnamed: J2.2, U2.8 (O+)
unnamed: J3.1, U3.7 (O-)
unnamed: J3.2, U3.8 (O+)
unnamed 23: LED_Connector1.2, R3.1; also elsewhere on the board

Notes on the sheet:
LED and Button
Voltage Regulator 5v
Vibration Controller
RF Module
Arduino
Voltage Monitor

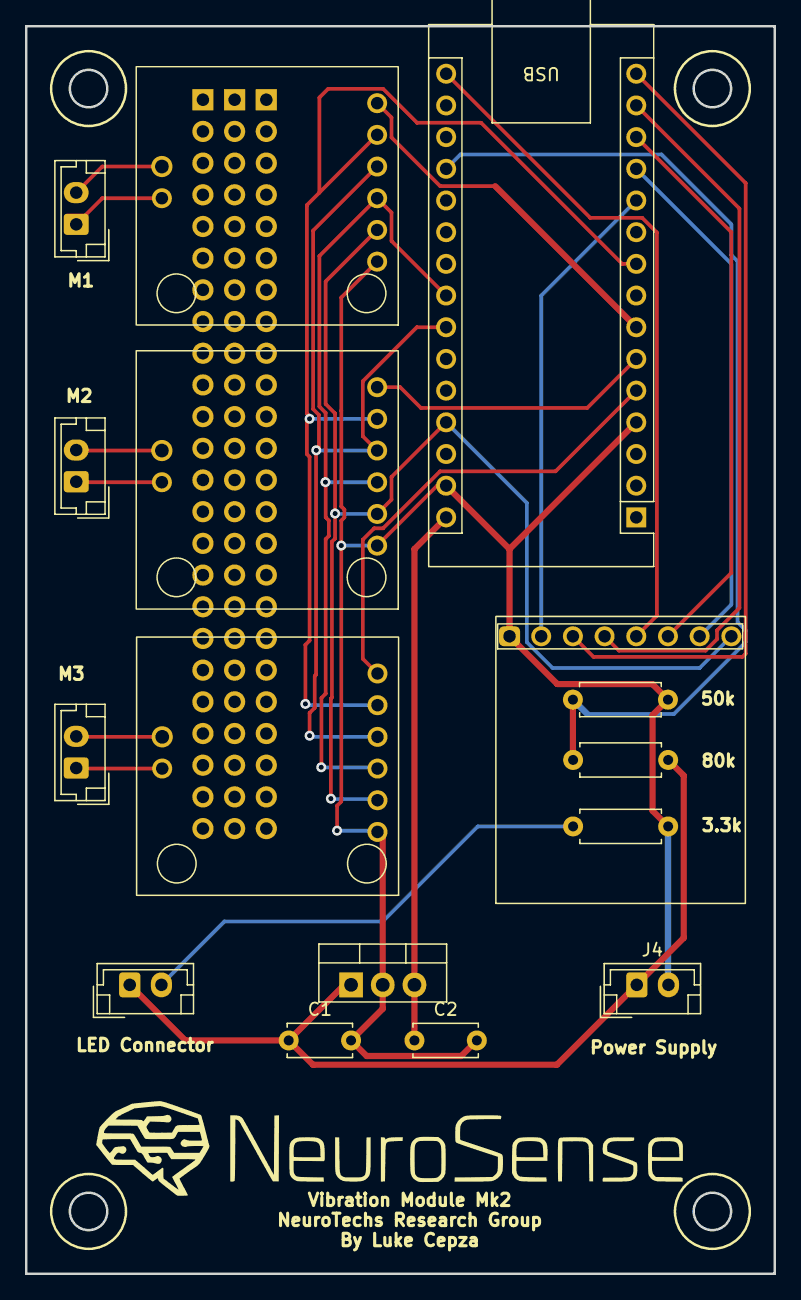
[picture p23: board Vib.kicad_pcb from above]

Board: 2 copper layers, 60.0 x 100.0 mm, 16 parts (0 on the bottom side), 24 nets.

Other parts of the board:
LED Connector: Conn_01x02_Male; JST_EH_B2B-EH-A_1x02_P2.50mm_Vertical

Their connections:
/v_BAT: LED Connector.1; also elsewhere on the board
unnamed 23: LED Connector.2; also elsewhere on the board

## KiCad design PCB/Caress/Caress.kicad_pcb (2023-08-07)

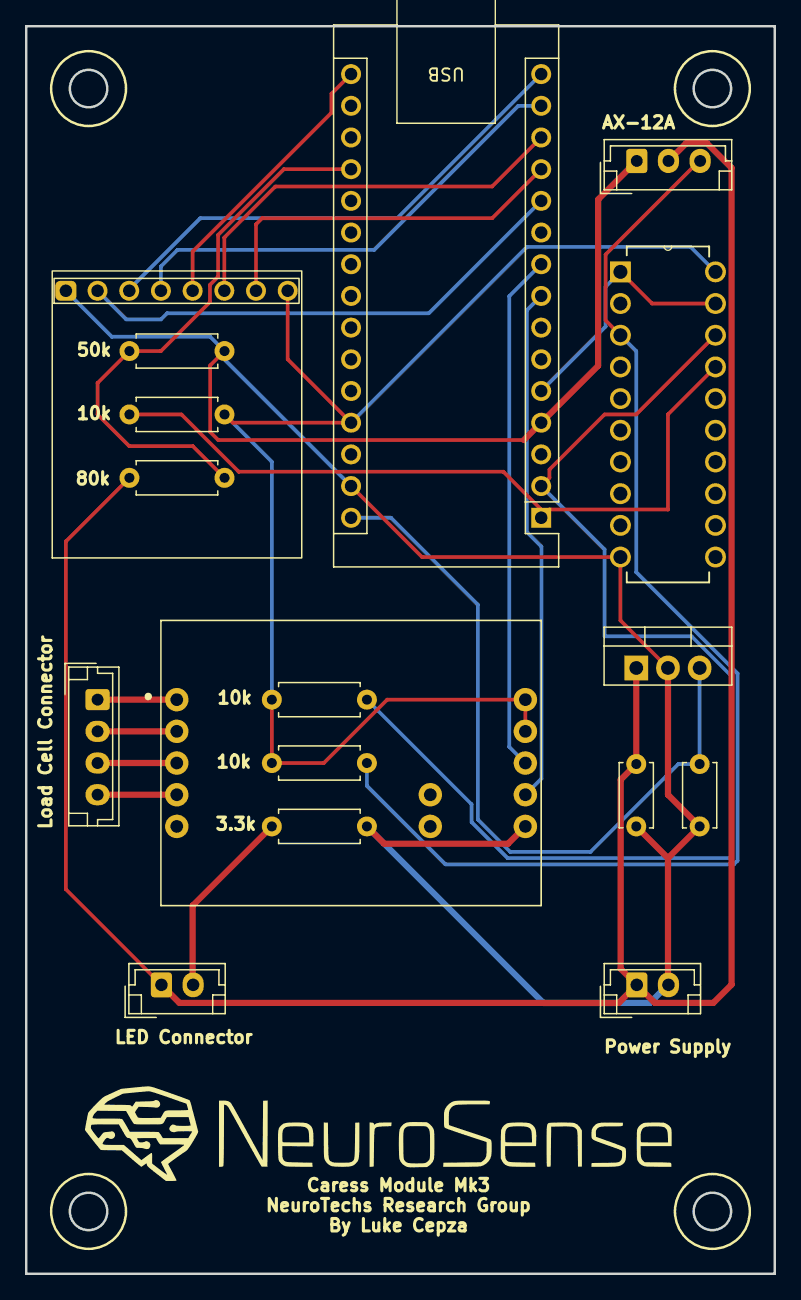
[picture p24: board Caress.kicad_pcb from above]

Board: 2 copper layers, 60.0 x 100.0 mm, 17 parts (0 on the bottom side), 22 nets.

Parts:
A1: Arduino_Nano_v3.x; Arduino_Nano
C1: 33uF; C_Disc_D5.0mm_W2.5mm_P5.00mm
C2: 10uF; C_Disc_D5.0mm_W2.5mm_P5.00mm
J1: LoadCellConnector; JST_EH_B4B-EH-A_1x04_P2.50mm_Vertical
J2: Conn_01x02_Pin; JST_EH_B2B-EH-A_1x02_P2.50mm_Vertical
J3: Conn_01x02_Male; JST_EH_B2B-EH-A_1x02_P2.50mm_Vertical
J4: Conn_AX12A; JST_EH_B3B-EH-A_1x03_P2.50mm_Vertical
R1: 80k; R_Axial_DIN0207_L6.3mm_D2.5mm_P7.62mm_Horizontal
R2: 50K; R_Axial_DIN0207_L6.3mm_D2.5mm_P7.62mm_Horizontal
R3: 3.3k; R_Axial_DIN0207_L6.3mm_D2.5mm_P7.62mm_Horizontal
R4, R5, R6: 10k; R_Axial_DIN0207_L6.3mm_D2.5mm_P7.62mm_Horizontal
U1: WRL-00691
U2: SEN-13879; SPARKFUN_SEN-13879
U3: LM7805_TO220; TO-220-3_Vertical
U4: SN74LS241N; DIP254P762X508-20

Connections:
+5V: A1.27 (+5V), R4.1, R5.1, R6.1, U1.8 (VCC), U2.9 (VCC), U2.10 (VDD), U4.20 (VCC)
+12V: C1.1, J2.1, J3.1, J4.2, R1.1, U3.1 (VI)
/A0_VBat: A1.19 (A0), R1.2, R2.1
/D0_1Y1: A1.2 (D0/RX), R5.2, U4.18 (1Y1)
/D1_2A4: A1.1 (D1/TX), R4.2, U4.17 (2A4)
/D2_G: A1.5 (D2), U4.1 (1~G), U4.19 (2G)
/D5_CLK: A1.8 (D5), U2.7 (CLK)
/D6_DAT: A1.9 (D6), U2.8 (DAT)
/D8_IRQ: A1.11 (D8), U1.2 (IRQ)
/D9_CE: A1.12 (D9), U1.7 (CE)
/D10_CSN: A1.13 (D10), U1.6 (CSN)
/D11_MOSI: A1.14 (D11), U1.4 (MOSI)
/D12_MISO: A1.15 (D12), U1.3 (MISO)
/D13_SCK: A1.16 (D13), U1.5 (SCK)
/VIN_5v: A1.30 (VIN), C2.1, U3.3 (VO)
GND: A1.4 (GND), A1.29 (GND), C1.2, C2.2, J3.2, J4.1, R2.2, R3.2, U1.1 (GND), U2.6 (GND), U3.2 (GND), U4.10 (GND)
unnamed: J1.1, U2.1 (RED)
unnamed: J1.2, U2.2 (BLK)
unnamed: J1.3, U2.3 (WHT)
unnamed: J1.4, U2.4 (GRN)
unnamed: J2.2, R3.1
unnamed: J4.3, R6.2, U4.3 (2Y4)

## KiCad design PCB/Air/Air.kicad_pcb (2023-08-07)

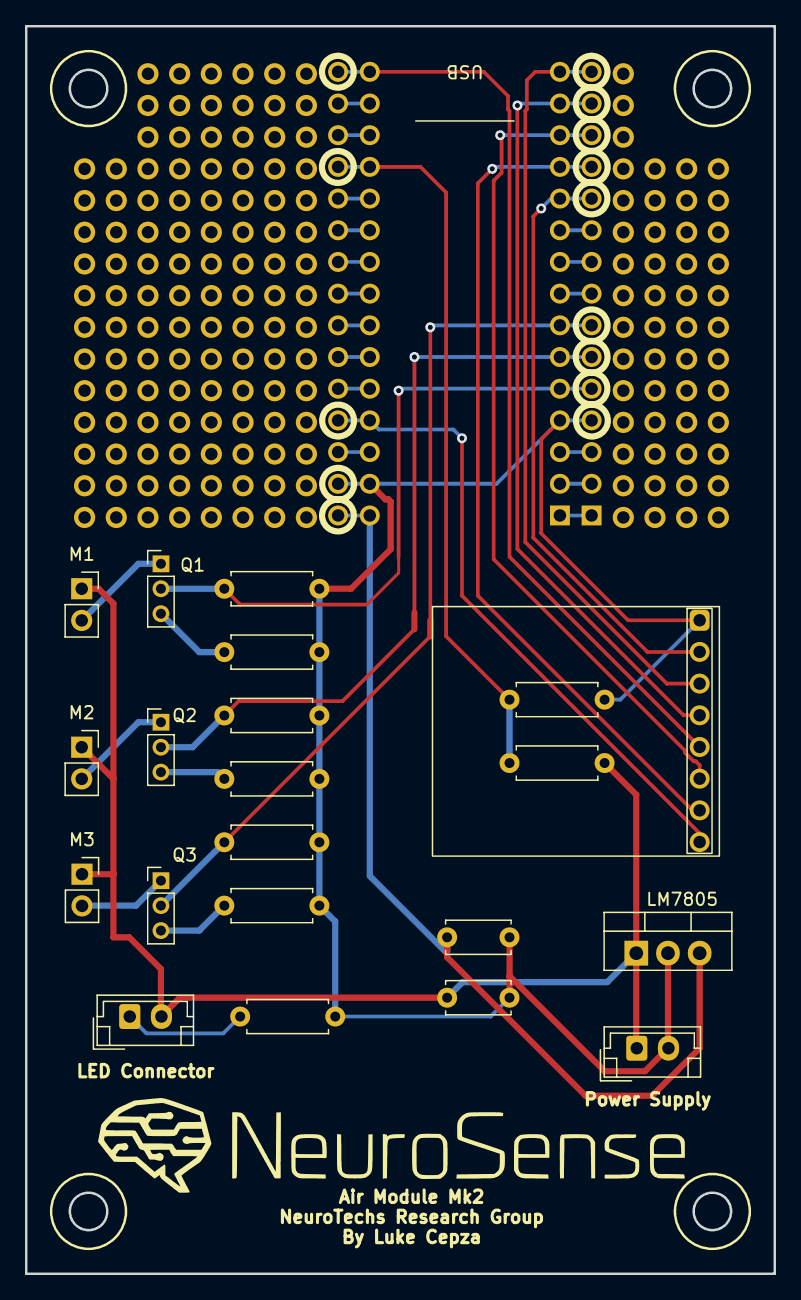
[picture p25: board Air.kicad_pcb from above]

Board: 2 copper layers, 60.0 x 100.0 mm, 22 parts (0 on the bottom side), 21 nets.

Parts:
A1: Arduino_Nano_v3.x; Arduino_Nano_Connectors side by
C1: 33uF; C_Disc_D5.0mm_W2.5mm_P5.00mm
C2: 10uF; C_Disc_D5.0mm_W2.5mm_P5.00mm
J1: LED; JST_EH_B2B-EH-A_1x02_P2.50mm_Vertical
J2: Battery; JST_EH_B2B-EH-A_1x02_P2.50mm_Vertical
LM7805: LM7805_TO220; TO-220-3_Vertical
M1, M2, M3: Fan; PinSocket_1x02_P2.54mm_Vertical
Q1, Q2, Q3: NPN; PinHeader_1x03_P2.00mm_Vertical
R1, R3, R8: 3.3 k; R_Axial_DIN0207_L6.3mm_D2.5mm_P7.62mm_Horizontal
R2, R7, R9: 100; R_Axial_DIN0207_L6.3mm_D2.5mm_P7.62mm_Horizontal
R4: 80k; R_Axial_DIN0207_L6.3mm_D2.5mm_P7.62mm_Horizontal
R5: 50K; R_Axial_DIN0207_L6.3mm_D2.5mm_P7.62mm_Horizontal
R6: 3.3k; R_Axial_DIN0207_L6.3mm_D2.5mm_P7.62mm_Horizontal
U2: WRL-00691

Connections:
+5V: A1.27 (+5V), U2.8 (VCC)
+12V: C1.1, J1.2, J2.1, LM7805.1 (VI), M1.1 (+), M2.1 (+), M3.1 (+), R4.1
/A0_VBat: A1.19 (A0), R4.2, R5.1
/D2_F1: A1.5 (D2), Q1.2 (B), R1.1
/D3_F2: A1.6 (D3), Q2.2 (B), R3.1
/D4_F3: A1.7 (D4), Q3.2 (B), R8.1
/D8_IRQ: A1.11 (D8), U2.2 (IRQ)
/D9_CE: A1.12 (D9), U2.7 (CE)
/D10_CSN: A1.13 (D10), U2.6 (CSN)
/D11_MOSI: A1.14 (D11), U2.4 (MOSI)
/D12_MISO: A1.15 (D12), U2.3 (MISO)
/D13_SCK: A1.16 (D13), U2.5 (SCK)
/VIN_5v: A1.30 (VIN), C2.1, LM7805.3 (VO)
GND: A1.4 (GND), A1.29 (GND), C1.2, C2.2, J2.2, LM7805.2 (GND), R1.2, R2.2, R3.2, R5.2, R6.2, R7.2, R8.2, R9.2, U2.1 (GND)
unnamed: J1.1, R6.1
unnamed: M1.2 (-), Q1.1 (C)
unnamed: M2.2 (-), Q2.1 (C)
unnamed: M3.2 (-), Q3.1 (C)
unnamed: Q1.3 (E), R2.1
unnamed: Q2.3 (E), R7.1
unnamed: Q3.3 (E), R9.1

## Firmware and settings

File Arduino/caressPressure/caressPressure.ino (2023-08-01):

// This device is a TX node aka the master
#include <SPI.h>
#include "printf.h"
#include "RF24.h"
// instance of radio
RF24 radio(9, 10); // using pin 9 for the CE pin, and pin 10 for the CSN pin

// Let these addresses be used for the pair
uint8_t address[][6] = {"M2T", "M2A", "M2V"};
int ang_01_Io, ang_02_Io, ten, dA;
int ang_01, ang_02;
int c, newtons, angle;
byte payload = 0x00;

unsigned long currentTime, previousTime, eltime;
double elapsedTime;
double input, output;
double TimeZero, currtime;
double Yt, Ut, setPoint;

boolean newDataReady = 0;
int serialPrintInterval = 0; // increase value to slow down serial print activity
double elTime;               // compute time elapsed from previous computation

//-----------------Servos-----------------//
// https://github.com/zcshiner/Dynamixel_Serial/blob/master/Dynamixel%20Institution%20V2.pdf
// https://github.com/zcshiner/Dynamixel_Serial
#include <Dynamixel_Serial.h>     // Library needed to control Dynamixal servo
#define SERVO_01 0x01             // ID of which we will set Dynamixel too
#define SERVO_02 0x02             // ID of which we will set Dynamixel too
#define SERVO_ControlPin 0x02     // Control pin of buffer chip, NOTE: this does not matter becasue we are not using a half to full contorl buffer.
#define SERVO_SET_Baudrate 500000 // Baud rate speed which the Dynamixel will be set too (57600)
#define CW_LIMIT_ANGLE 0x001      // lowest clockwise angle is 1, as when set to 0 it set servo to wheel mode
#define CCW_LIMIT_ANGLE 0x3FF     // Highest anit-clockwise angle is 0XFFF, as when set to 0 it set servo to wheel mode

//--------------Strain Gauge--------------//
// https://github.com/sparkfun/HX711-Load-Cell-Amplifier
// https://github.com/bogde/HX711
// https://github.com/olkal/HX711_ADC
#include <HX711_ADC.h>
const int HX711_dout = 4; // mcu > HX711 dout pin
const int HX711_sck = 5;  // mcu > HX711 sck pin
// HX711 constructor:
HX711_ADC LoadCell(HX711_dout, HX711_sck);
long stabilizingtime = 2000; // preciscion right after power-up can be improved by adding a few seconds of stabilizing time
boolean _tare = true;        // set this to false if you don't want tare to be performed in the next step
bool cal1 = false;
bool cal2 = false;
boolean _resume = false;
unsigned long t = 0;

//****************************SET UP******************************//
void setup()
{
    //------------------Radio ------------------//
    // initialize the transceiver on the SPI bus
    Serial.begin(500000);
    while (!Serial)
    {
        // some boards need to wait to ensure access to serial over USB
    }
    if (!radio.begin())
    {
        Serial.println(F("radio hardware is not responding!!"));
        delay(200);
        while (1)
        {
        } // hold in infinite loop
    }
    radio.setPALevel(RF24_PA_LOW);         // RF24_PA_MAX is default.
    radio.setPayloadSize(sizeof(payload)); // float datatype occupies 2 bytes
    radio.openReadingPipe(1, address[0]);  // pipe 1/6 - "M2T" - Master to Touch
    radio.startListening();                // put radio in RX mode

    //-----------------Servos-----------------//
    Dynamixel.begin(SERVO_SET_Baudrate);                                                  // We now need to set Ardiuno to the new Baudrate speed
    Serial.println("CLEARDATA");                                                          // column headers
    Serial.println("LABEL, RMotor, LMotor, Yt, Ut, Time, CurrTime, RelativeTime, Phase"); // column headers
    Serial.println("ResetTimer");                                                         // column headers
    Serial.println("DATA, TIME, TIMER");
    Dynamixel.setDirectionPin(SERVO_ControlPin);
    Serial.print(","); // Optional. Set direction control pin
    Dynamixel.setMode(SERVO_02, SERVO, CW_LIMIT_ANGLE, CCW_LIMIT_ANGLE);
    Serial.print(",");                                                   // set mode to SERVO and set angle limits
    Dynamixel.setMode(SERVO_01, SERVO, CW_LIMIT_ANGLE, CCW_LIMIT_ANGLE); // set mode to SERVO and set angle limits
    //--------------Strain Gauge--------------//
    LoadCell.begin();
    LoadCell.start(stabilizingtime, _tare);
    while (!LoadCell.update())
    {
    }
    if (LoadCell.getTareTimeoutFlag() || LoadCell.getSignalTimeoutFlag())
    {
        Serial.println("Timeout, check MCU>HX711 wiring and pin designations");
        while (1)
            ;
    }
    else
    {
        LoadCell.setCalFactor(-461); // user set calibration value (float), initial value 1.0 may be used for this sketch
                                     // Serial.println("Startup is complete");
    }
    distend();
} //**************************END SETUP*******************************//

//**************************** LOOP *********************************//
void loop()
{
    uint8_t pipe;
    if (radio.available(&pipe)) {             // is there a payload? get the pipe number that recieved it
        uint8_t bytes = radio.getPayloadSize(); // get the size of the payload
        radio.read(&payload, bytes);            // fetch payload from FIFO +++++++++++++++
        SerialEventWrite(payload);
    }

} //**************************** END LOOP ***************************//

// Aumentar la tension de forma estatica.
int tense(double newtons, double ten)
{
    ang_02_Io = 1023;
    ang_01_Io = 0;
    Dynamixel.servo(SERVO_01, ang_01_Io, 0x060);
    Dynamixel.servo(SERVO_02, ang_02_Io, 0x060);
    delay(1000);
    ten = 0;
    int m = 20; // Proporcion tensante, es la velocidad a la que se tensa.
    Serial.println("t = " + String(eltime) + " YT = " + String(Yt) + " m = " + String(m) + " da = " + String(dA) + " A02 = " + String(ang_02_Io));
    eltime = 0;
    previousTime = millis();
    while (eltime < 7000)
    {
        eltime = millis() - previousTime;
        Yt = ReadStrainGauge();

        if (Yt < newtons - .02 * newtons)
        {
            ten = ten + m;
        }
        else if (Yt > newtons + .02 * newtons)
        {
            ten = ten - m;
            m = 1; // newtons/200;
        }
        if (ten > 1024 && ten <= 1536)
        { // THIRD ANGLE
            ang_01 = 1023;
            ang_02 = ang_02_Io - ten + 1023;
        }
        else if (ten > 512 && ten <= 1024)
        { // SECOND ANGLE
            ang_02 = 1023;
            ang_01 = ang_01_Io + ten;
        }
        else if (ten > 0 && ten <= 512)
        { // FIRST ANGLE
            ang_02 = 1023;
            ang_01 = ang_01_Io + ten;
        }
        Dynamixel.servo(SERVO_01, ang_01, 0x060);
        Dynamixel.servo(SERVO_02, ang_02, 0x060);
        Serial.println();
        // Tolerance error 2%
        dA = ten;
        delay(m * 5); // Cuando se esta tensando por primera vez, la duración entre cado paso de tensado es mayor que cuando ya se ha
        // sobrepasado el nivel de interes.
        Serial.print("t = " + String(eltime) + " YT = " + String(Yt) + " m = " + String(m) + " ten = " + String(ten) + " A02 = " + String(ang_02_Io));
    }
    return ten;
}

void stim_right(int newtons)
{   
    // newtons = 203.94;
    eltime = 0;
    previousTime = millis();
    int lag = 0;
    int cur_ang = 0;
    int mov = 5;
    int m = newtons / 200; //This constant is to adjust the tension if it is decaying
    ;
    while ((eltime < 6000) && ((ang_01 - cur_ang) > 0) && ((ang_02 - cur_ang) > 0))
    {
        cur_ang = cur_ang + mov;
        if (Yt < newtons - .02 * newtons)
        {
            lag = lag + m;
        }
        if (Yt > newtons + .02 * newtons)
        {
            lag = lag - m;
        }
        eltime = millis() - previousTime;
        Yt = ReadStrainGauge();
        Serial.print("t = " + String(eltime) + " YT = " + String(Yt) + " ten = " + String(ten) + " da = " + String(dA) + " A02 = " + String(ang_02_Io));
        Dynamixel.servo(SERVO_01, ang_01 - cur_ang +lag, 0x050);  Dynamixel.servo(SERVO_02, ang_02 - cur_ang, 0x050); Serial.println("");
        delay(40);
    }
}

void stim(int newtons)
{   
    // newtons = 203.94;
    eltime = 0;
    previousTime = millis();
    int wait = 4;
    int vel = 600;
    int lag1 = 0;
    int lag2 = 0;
    int cur_ang = 0;
    int mov = 20;
    int m = newtons / 100; //This constant is to adjust the tension if it is decaying
    bool right = true;
    while ((eltime < 7000))
    {
        eltime = millis() - previousTime;
        if (right){
          cur_ang = cur_ang + mov;
          if (((ang_01 - cur_ang + lag1) > 0) && ((ang_02 - cur_ang + lag2) > 0))
          {
              Yt = ReadStrainGauge();
              if (Yt < newtons - .02 * newtons)
                  {lag1 = lag1 + m;}
              else if (Yt > newtons + .02 * newtons)
                  {lag1 = lag1 - m;}
              Dynamixel.servo(SERVO_01, ang_01 - cur_ang +lag1, vel);  Dynamixel.servo(SERVO_02, ang_02 - cur_ang + lag2, vel); Serial.println("");
              Serial.print("t = " + String(eltime) + " YT = " + String(Yt) + " cur_ang ="+String(cur_ang)+" cur_ang_1 = " + String(ang_01 - cur_ang +lag1) + " cur_ang_2 = " + String(ang_02 - cur_ang + lag2));
              delay(wait);
          }
          else {
            cur_ang = cur_ang - mov;
            right = not right;
          }    
        }
        else if (not right){
          cur_ang = cur_ang - mov;
        if (((ang_01 - cur_ang + lag1) < 1024) && ((ang_02 - cur_ang + lag2) < 1024) && (not right)) {
            Yt = ReadStrainGauge();
            if (Yt < newtons - .02 * newtons)
                {lag2 = lag2 - m;}
            else if (Yt > newtons + .02 * newtons)
                {lag2 = lag2 + m;}
            Dynamixel.servo(SERVO_01, ang_01 - cur_ang +lag1, vel);  Dynamixel.servo(SERVO_02, ang_02 - cur_ang + lag2, vel);  Serial.println(""); 
            Serial.print("t = " + String(eltime) + " YT = " + String(Yt) + " cur_ang ="+String(cur_ang)+" cur_ang_1 = " + String(ang_01 - cur_ang +lag1) + " cur_ang_2 = " + String(ang_02 - cur_ang + lag2));
            delay(wait);
        }
        else {
            right = not right;
            cur_ang = cur_ang + mov;
        }
    }
}
}
// programación completa del prototipo
void SerialEventWrite(byte rec)
{
    // 200 gramos
    if (rec == 0x0D) //
    {
        zerotare();
        ten = 0;
        ten = tense(200, ten);
    }
    else if (rec == 0x01)
    {
        stim_right(200);
        distend();
    }
    // 300 gramos
    else if (rec == 0x0E)
    {
        zerotare();
        ten = 0x200;
        dA = tense(300, ten);
    }
    else if (rec == 0x02)
    {
        stim_right(300);
        distend();
    }
    // 400 gramos
    else if (rec == 0x0F)
    {
        zerotare();
        ten = 0x250;
        dA = tense(400, ten);
    }
    else if (rec == 0x03)
    {
        stim_right(400);
        distend();
    }
    // 600 gramos
    else if (rec == 0x10)
    {
        zerotare();
        ten = 0x300;
        dA = tense(600, ten);
    }
    else if (rec == 0x04)
    {
        stim(600);
        distend();
    }
}
// Quitar el peso del brazo
void zerotare()
{
    LoadCell.start(stabilizingtime, _tare); // zero tare
    unsigned long relativeTime = millis();  // Tiempo en el que comenzo el movimiento
}
// lectura del peso del brazo/pierna
double ReadStrainGauge()
{
    while (!newDataReady)
    {
        if (LoadCell.update())
            newDataReady = true;
    }
    if (newDataReady)
    {
        if (millis() > t + serialPrintInterval)
        {
            double Yt = LoadCell.getData();
            newDataReady = 0;
            t = millis();
            return Yt;
        }
    }
}
void distend()
{
    ang_02_Io = 1023;
    ang_01_Io = 0;
    Dynamixel.servo(SERVO_01, ang_01_Io, 0x300);
    Dynamixel.servo(SERVO_02, ang_02_Io, 0x300);
    delay(5000);
}

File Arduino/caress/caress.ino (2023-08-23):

// This device is the Carees node

// RF module libraries
#include <SPI.h>
#include "printf.h"
#include "RF24.h"
RF24 radio(9, 10);                                // Arduino pin 9 for the CE pin and pin 10 for the CSN pin
uint8_t address[][6] = {"M2T", "M2A", "M2V"};     // Addresses for the pair of modules (Master to Touch | Master to Air | Master to Vibration)
byte payload = 0x00;

// Servo-motors libraries
//Libraries used: https://github.com/zcshiner/Dynamixel_Serial/blob/master/Dynamixel%20Institution%20V2.pdf
#include <Dynamixel_Serial.h>     // Library needed to control Dynamixal servo
#define SERVO_01 0x01             // ID of which we will set Dynamixel too
#define SERVO_02 0x02             // ID of which we will set Dynamixel too
#define SERVO_ControlPin 0x02     // Control pin of buffer chip, NOTE: this does not matter becasue we are not using a half to full contorl buffer.
#define SERVO_SET_Baudrate 500000 // Baud rate speed which the Dynamixel will be set too (57600)
#define CW_LIMIT_ANGLE 0x001      // lowest clockwise angle is 1, as when set to 0 it set servo to wheel mode
#define CCW_LIMIT_ANGLE 0x3FF     // Highest anit-clockwise angle is 0XFFF, as when set to 0 it set servo to wheel mode

float ang_01_Io, ang_r, ang_l;
int ang_01, ang_02;
byte pos = 0;
boolean newDataReady = 0;
int serialPrintInterval = 0;    // increase value to slow down serial print activity
double elTime;                  // compute time elapsed from previous computation


void setup(){
  Serial.begin(SERVO_SET_Baudrate);   // baudrate equal to one in servo-motors (500000)

  // --- Initialize Servo-motores --- //
  Dynamixel.begin(SERVO_SET_Baudrate);  delay(1); // We now need to set Ardiuno to the new Baudrate speed
  Dynamixel.setDirectionPin(SERVO_ControlPin);  delay(1);
  Dynamixel.setMode(SERVO_01, SERVO, CW_LIMIT_ANGLE, CCW_LIMIT_ANGLE);  delay(1); // set mode to SERVO and set angle limits 
  Dynamixel.setMode(SERVO_02, SERVO, CW_LIMIT_ANGLE, CCW_LIMIT_ANGLE);  delay(1);
  zeropos();  // set motors to initial position
  
  // --- From RF24 library example: GettingStarted --- //
  // configure RF
  while (!Serial){
    // some boards need to wait to ensure access to serial over USB
  }
  // initialize the transceiver on the SPI bus
  if (!radio.begin()){
    Serial.println(F("radio hardware is not responding!!"));
    delay(200);
    while (1){} // hold in infinite loop
  }
  radio.setPALevel(RF24_PA_LOW);         // RF24_PA_MAX is default.
  radio.setPayloadSize(sizeof(payload)); // float datatype occupies 2 bytes
  radio.openReadingPipe(1, address[0]);  // pipe 1 "M2T" - Master to Touch
  radio.startListening();                // put radio in RX mode
}


void loop(){
  uint8_t pipe;
  if (radio.available(&pipe)) {             // is there a payload? get the pipe number that recieved it
    uint8_t bytes = radio.getPayloadSize(); // get the size of the payload
    radio.read(&payload, bytes);            // fetch payload from FIFO 
    SerialEventWrite(payload);
  }
}


void SerialEventWrite(byte rec){
  // function SerialEventWrite reads the label/code (or payload) received from Master module
  // and writes their corresponding motor velcity
    if (rec == 0x01){
      stim(60,1); 
    }
    else if (rec == 0x02){
      stim(90,1);
    }
    else if (rec == 0x03){
      stim(120,1);
    }
    else if (rec == 0x04){
      stim(180,1);
    }
}


void stim(int vel, int t){
  // function stim calculates the turning angle in 1 second for the servo-motor
  // according to the velocity of the stimuli
    ang_r = int(ang_01_Io + vel * t * 2.27);
    ang_l = int(ang_01_Io - vel * t * 2.27);
    if (ang_r > 1000){          // If the next angle is larger than possible,
      stim_angle(ang_l,vel);   
    } else {                      // Change direction.
      stim_angle(ang_r,vel);
    }
}


void stim_angle(int ang, int vel){
  // function stim_angle uses library function Dynamixel.servo to activate servo-motors with the corresponding
  // velocity for moving the calculated angle
    Dynamixel.servo(SERVO_01, ang, vel);    delay(1);   //move motors to desired angle at specific velocity
    Dynamixel.servo(SERVO_02, ang, vel);    delay(1);
    ang_01_Io = ang;
}


void zeropos(){
  // function zeropos initializes servo-motors in "home" position
    ang_01_Io = 1023;
    Dynamixel.servo(SERVO_01, ang_01_Io, 0x150);  delay(1);   //move motors to initial position
    Dynamixel.servo(SERVO_02, ang_01_Io, 0x150);  delay(1);
}

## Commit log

2022-02-26 last version of vibrations
    [vibration.ino]
2022-03-17 Cambiso para que el tensado se haga desde el master, y el prototipo de caricia ahora funciona con modo servo
2022-05-19 Master_v4.ino
    New label codes for Threshold (33041) and Paro (33042).
    Some messages show in LCD screen were updated.
    Missing: How to send TH and PARO label to two modules?
    [master.ino]
2022-06-02 Cambiso recientes para conectividad OV > Python > Arduino
2022-06-02 Adecuación aire para OV > Python > Arduino
2022-11-08 20_stimuli
    Se eliminaron las líneas de threshold, se arreglaron las líneas de estímulos dentro de un for que mandará los 20 estímulos.
2022-11-08 Validaction_vibraciones
    Quitar el threshold.
    Solo 20 estímulos en un for.
2022-11-08 Vibracinoes
    Experimento comienza 20s después de Play en OpenViBe.
2022-11-08 Vibration mejorado, No ocupa etiqueta de no-threshold pero puede usar threshold. Depende OV.
    [vibration.ino]
2022-11-08 no-threshold
    Se adaptó para funcionar con y sin threshold (probar primero).
2022-11-09 reacomodo
    Re-agrupación de las etiquetas por cada módulo
2022-11-09 Corrección 2 líneas
    2 líneas mal re-acomodadas, arregladas
    [master.ino]
2022-11-10 Vibra-Validation flag
    Se agrega a código Lua y Arduino Vib la etiqueta de Validación de Vib: 33041.
    También se agregó a maste para aire (33044) y vibraciones (33041).
2022-11-10 Error Address
    error en address de la validación de aire corregido
    [master.ino]
2022-11-10 Hice algunios cambios, ahora se ejecuta desde el prompt y como argumento se pone el puerto. ej. python conection_ov_ino.py COM3
2022-11-10 Muestra todos los errores
    [conection_ov_ino.py]
2022-11-10 Regreso al anterior
    Se regresó a la versión anterior, antes del último cambio
2022-11-11 Validación
    Editado para agregar un arreglo de intensidades.
    [air.ino]
2022-11-12 touch updated, asi ya jala con el rf nomas que tnga el brazo puesto
2022-11-12 Caricia 20 estimulos
    Se creó un uevo programa de caricia para los 20 estímulos
2022-11-12 Variables
    Se agregaron variables entre otras funciones que faltaban para probar para el de caricia.
    No funcionó. Seguir probando.
2022-11-14 End
    se agregó un END que faltaba.
2022-11-14 Muchos cambios, idk que tanto hice jajajalv
2022-11-14 tiempos
    Aire: modificación tiempos interestímulos
    Caricia: duración de tiempos para mandar etiquetas.
    Vibr: cambio de tiempo de envío de etiqueta de validación de 5 a 15s.
2023-02-24 Version que no necesita LSL; Hace falta probarlo
2023-04-19 Mejore funcionamiento de openvibe
2023-07-19 Added PCB Diagrams
    [Air.kicad_pcb, Air.kicad_sch, Caress.kicad_pcb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]
2023-07-19 Changed some folders and added designs of two prototypes
    [18650.SLDPRT, A_BatteryBox.SLDPRT, A_BatteryBoxLid.SLDPRT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]
2023-08-01 Cambios de DCNLaptop
2023-08-02 Fixed folders and added validation data
    [caress.ino, caressPressure.ino]
2023-08-05 Updated PCB files; added desing files for caress and vibration
    [Air-B_Cu.gbr, Air-B_Mask.gbr, Air-B_Silkscreen.gbr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]
2023-08-05 Added Vibration ElectroBox files
    [V_BatteryBox.SLDPRT, V_BatteryBoxLid.SLDPRT, V_ElectroBox.SLDPRT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]
